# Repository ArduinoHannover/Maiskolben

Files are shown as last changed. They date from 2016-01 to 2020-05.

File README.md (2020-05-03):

# Maiskolben

## SMD Lötstation, kompatibel zu Weller-Lötspitzen

Weller baut seit Jahren *die* Lötstationen für den professionellen Bereich.
Die WMRP/WXRP-Stationen heben sich durch ihre aktiven Lötspitzen von anderen Produkten ab.
Mit einer außergewöhnlich kurzen Aufheizzeit im Sekundenbereich, einer direkt in der Spitze integrierten Temperaturmessung und dementsprechend schnelle Nachregulierung in Sekundenbruchteilen sind die Spitzen in der Industrie äußerst beliebt.
Die Spitzen selbst sind für 40€ im Handel erhältlich, die original Weller-Station kostet an die 600€.
Für den einfachen Maker oder Hobbyist auf keinen Fall ein Produkt, das beim Onlineshopping ohne weitere Überlegungen in den Warenkorb wandert.
Der *Maiskolben* hingegen ist eine erschwingliche Lösung für lediglich 40€, mit der die Spitzen ebenso angesteuert werden können.

* Betrieb mit 12V Netzteil (oder bis zu 24V mit Fertigplatine) oder 3s LiPo (Modellbau-Akku)
* Spannungsüberwachung (bei Akku für alle 3 Zellen und automatische Abschaltung bei zu geringer Ladung)
* Einfaches Wechseln von Spitzen mittels Klinken-Buchse/-Kabel
* 3 individuelle Temperatur-Presets
* Temperaturbereich von 200-450°C
* Gut ablesbares Farbdisplay mit allen nötigen Informationen
* Auto-Standby (entweder sensor- oder zeitgesteuert auf 150°C)
* Auto-Wakeup (entweder sensorgesteuert oder durch Berühren von Lötschwamm, Messingwolle oder Lötstelle)
* USB-Schnittstelle zur Überwachung oder Steuerung mittels PC
* Potentialausgleich-/ESD-Buchse (über 1MΩ an GND)
* Optisches Feedback der Heizleistung durch LED
* Open-Source-Software auf Basis von Arduino
* Software-Update kann per USB eingespielt werden

*Zu erwerben bei [HannIO](https://hannio.org).*

## Stromzufuhr

Die Stromzufuhr wird wahlweise über die Hohlstecker-Buchse (10-24V) *ODER* die JST-XH4 (11,1V) Buchse angeschlossen.
Bei Versionen < 3.0 niemals beide gleichzeitig anschließen!
Der Lötkolben (Weller RT-XX, z.B. RT-1 für feine Lötarbeiten) wird über die Klinkenbuchse mit einer Verlängerung angesteckt.

## Display

Das Display zeigt mittig in weißer Schrift die Soll-Temperatur, darunter, sofern eine Spitze eingesteckt ist, die aktuelle Ist-Temperatur.
Bei eingeschaltetem Lötkolben erscheint zusätzlich noch die Zeit, nach der sich der Lötkolben automatisch in den Standby versetzt.
Der Balken am oberen Bildschirmrand spiegelt die Ist-Temperatur wieder.
Oben Links wird die Spannung bzw. die Ladezustände der einzelnen Zellen angezeigt.
Links wird durch das Power-Symbol der aktuelle Zustand (aus = rot, Standby = gelb, an = grün) signalisiert.
Am unteren Rand sind die drei Presets zu sehen.

## Bedienung

Nach dem Anstecken von Netzteil und Lötspitze kann die Station durch halten der Power-Taste (unten rechts) eingeschaltet werden.
Basierend auf der letzten Einstellung wird die angezeigte Soll- (Power-Symbol grün) oder die Standby-Temperatur (Symbol gelb) angefahren.

Mittels der Tasten rechts vom Display (Pfeile) lässt sich die Soll-Temperatur nach oben und unten korrigieren.
Sollte einer der Pfeile auf dem Display ausgegraut sein, so lässt sich über diese Temperatur hinaus keine weitere Änderung mehr vornehmen (200 ≥ T ≥ 450).

### Presets

Mittels der Preset-Tasten unter dem Bildschirm lassen sich voreingestellte Temperaturen als Soll-Temperatur setzen und die Station gleichzeitig aus dem Standby aufwecken.
Durch Gedrückthalten einer der drei Tasten wird der dort gespeicherte Wert durch die aktuelle Soll-Temperatur überschrieben.
Wird die Power-Taste nur kurz gedrückt, so wird der Standby-Zustand umgeschaltet.

### Startmenü

Es gibt ein verstecktes Menü, in dem sich der automatische Standby abschalten und ein automatisches Hochfahren auf die zuletzt gewählte Temperatur bei Spannungsversorgung aktiviert werden können. Um in dieses Menü zu gelangen, muss beim Anlegen der Spannungsversorgung während des Blinkens der LED die Power-Taste betätigt werden.

## Fehlermeldungen

#### USB power only/Connect power supply; Power too low/Connect power >5V
Die Lötstation wird entweder nur über USB oder eine Spannungsquelle mit knapp 5V versorgt.
Zum Betrieb wird ein adäquates Netzteil oder Akku benötigt (≥40W)

#### NO TIP; No tip connected/Tip slipped out?
Es wurde keine Spitze eingesteckt oder nicht erkannt.
Es kann sein, dass die Spitze defekt ist oder nicht richtig in der Buchse steckt.

#### Temperature dropped/Tip slipped out?
Es wurde ein zu großer Temperaturabfall bemerkt und die Wahrscheinlichkeit besteht, dass die Spitze leicht aus der Buchse herausgerutscht ist.
Durch das Herausrutschen kann eine Verbindung zwischen Masse und dem Sensor hergestellt werden, sodass die erkannte Temperatur beim Offset von 24°C liegt.

#### Not heating/Weak power source or short
Entweder kann die Stromversorgung nicht genug Leistung bringen, um die Spitze in einem angemessenen Zeitraum aufzuheizen oder es liegt wie bei obigem Fehler ein Kurzschluss von Masse und Sensor vor.

#### Battery low/Replace or charge
Der Akku hat auf mindestens einer Zelle eine zu geringe Spannung und sollte ersetzt oder geladen werden.

Fehlermeldungen müssen durch OK bestätigt werden.
Die Fehlermeldungen können nicht unterdrückt werden, sollte allerdings mehrfach hintereinander eine Meldung bestätigt und die Station wieder eingeschaltet werden, kann dies zu übermäßigem Erwärmen der Lötspitze führen.

## Software-Update

Um die aktuellste Software auf den Maiskolbe zu übertragen, muss zunächst die [Arduino-IDE](https://www.arduino.cc/en/Main/Software) heruntergeladen werden.
In diesem Repository befinden sich zwei Programme, zum einen Maiskolben_LCD für die Hardware-Revision 1.0 und Maiskolben_TFT für Hardware-Revisionen ab 1.5.
Die .ino Datei kann mit Arduino geöffnet werden.
Der Serielle-Port muss nach Herstellen einer Verbindung zwischen Maiskolben und PC unter _Werkzeuge_ > _Port_ ausgewählt werden.
Unter Umständen muss zuvor noch der [CH340 Treiber](http://www.wch.cn/download/CH341SER_ZIP.html) für den USB-Seriell-Wandler installiert werden.
Als _Board_ sollte _Arduino Nano_ mit _Prozessor: ATmega328 (Old Bootloader)_ ausgewählt werden.
Über _Sketch_ > _Hochladen_ bzw. den Pfeil nach Rechts in der oberen Leiste kann das Programm übertragen werden.

### Bibliotheken

Unter Umständen müssen vorher folgende Libraries noch über _Sketch_ > _Bibliothek einbinden_ > _.ZIP Bibliothek hinzufügen..._ eingebunden werden:

* [TimerOne](https://github.com/PaulStoffregen/TimerOne)
* [PID_v1](https://github.com/br3ttb/Arduino-PID-Library/)
* ~~[Adafruit_ST7735](https://github.com/adafruit/Adafruit-ST7735-Library)~~ (Software Version < 3.0)
* [TFT_ILI9163C](https://github.com/ArduinoHannover/TFT_ILI9163C)
* [Adafruit_GFX](https://github.com/adafruit/Adafruit-GFX-Library)

Dafür muss von den entsprechenden Seiten zuvor die ZIP heruntergeladen werden.
Diese kann dann in dem Dateibrowser, der sich nach obiger Anleitung öffnet, selektiert werden.

### Changelog

* 3.1
  * Option im Menü eingebaut, um zwischen Fahrenheit und Celsius zu wechseln
  * Bug behoben, der bei falsch initialisiertem EEPROM die Temperaturberechnung nicht richtig ausgeführt hat
* 3.0
  * Geänderte Display-Bibliothek (vgl. [Abschnitt Bibliotheken](#Bibliotheken))
  * Mehr Strings im Flash statt im RAM
  * Anpassungen um einen Maiskolben V3.2 im LiPo-Betrieb vollständig abzuschalten
  * Limitierung der Minimaltemperatur auf 200°C
  * `°C` wird mit bei Soll- und Ist-Temperatur angezeigt
  * Interne Temperatur-Kalibrierung für jeden Maiskolben individuell (bisher nur für Kalibrierung ab Werk)
* 2.8
  * Zeilenhöhe des Balkens ist nun variabel
  * Temperaturen als `#define` gesetzt
  * Temperaturberechnung wieder angepasst
  * EEPROM-Fehler behoben
* 2.7
  * TFT-Reset eingebaut
* 2.6
  * Schreibfehler korrigiert
  * Anpassungen an unterschiedliche Hardwareausführungen verbessert
  * Beim Aufruf des Menüs kommt man nach schließen direkt zum Programm
  * Autopower verfeinert
* 2.5
  * Interne Testroutinen hinzugefügt
  * Anpassung an Hardwarerevision ≥ 3.0
  * Wattanzeige hinzugefügt
* 2.4
  * Spannungsanzeige gegen Steckersymbol getauscht
* 2.3
  * Anpassung an unterschiedliche Display-Treiber (BGR/RGB)
  * Geänderte Temperaturmessung
* 2.1
  * Bidirektionale Steuerung über serielle Schnittstelle
* 2.0
  * Initiale Version für GitHub (TFT)
  * Auto-Standby hinzugefügt
  * Parameter angepasst

### Achtung!

Zur eigenen Sicherheit vor einem Software-Update die Lötspitze entfernen.
Zwar wird die Heizspannung beim Übertragen deaktiviert, dennoch kann es vereinzelt zu Fehlfunktionen und dadurch bedingtem unbeschränkten Aufheizen der Spitze kommen.

Modifikationen an der Software sind auf eigene Gefahr des Nutzers.

## Umbauten

Nachfolgend werden Modifikationen beschrieben, die die Funktionen des Maiskolben erweitern.
Für eigens durchgeführte Änderungen kann keine Haftung übernommen werden.

### Ablage-Sensor nachrüsten

Statt des automatischen Standbys nach einer bestimmten Zeit kann auch der Standby durch einen Ablage-Sensor erzwungen werden.
Auf der Platine befinden sich Kontakte mit STBY, 5V und GND.
Um den Standby zu aktivieren muss STBY mit GND verbunden werden, um wieder aufzuwachen muss die Verbindung getrennt werden.
Das Schalten von STBY nach GND kann entweder durch einen Schalter erfolgen, der beim auflegen der Spitze auslöst, alternativ mit einem Hall- oder Reed-Sensor.
Für letzteres muss an dem Ende des Klinken-Kabels, an dem die Spitze eingesteckt wird, ein Magnet angebracht werden, der den Sensor dann auslöst.

### Stromversorgungs-Schalter

Ab Hardware-Revision 1.5 gibt es auf der Platinenunterseite eine Lötbrücke mit der Beschriftung ON/OFF.
Bis einschließlich Revision 1.9 wird beim Durchtrennen dieser Brücke die gesamte Stromversorgung unterbrochen.
Ab Revision 1.11 wird hingegen nur noch die Zuleitung des LiPos getrennt.
An den beiden Lötpunkten können nach dem Durchtrennen der Leiterbahn Kabel zu einem Schalter gelötet werden, mit dem sich die Stromversorgung unterbrechen lässt.

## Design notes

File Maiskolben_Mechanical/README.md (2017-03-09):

# Dateien für 3D-Druck- oder Lasercut-Gehäuse

Sofern die Dateien nicht den Zusatz "THT" enthalten, sind diese für die fertig gelöteten Station im Shop geeignet. Dateien mit "THT" hingegen nur für den Bausatz (siehe [Maiskolben_THT](https://github.com/ArduinoHannover/Maiskolben/tree/master/Maiskolben_THT)).

## Lasercut-Gehäuse

Die `_lasercut`-Dateien eignen sich für 3mm Material (klares Plexiglas wird für die Front empfohlen, alternativ Ausschnitt für das Display vorsehen). Beim THT Gehäuse sind zudem noch 6 der Button Caps (3D-Druck) notwendig.

## Eigenes/3D-Druck Gehäuse

Die `_outlines`-Dateien, respektive die .obj-Dateien sind 2D-/3D-Modelle, die zum Erstellen von eigenen Gehäusen genutzt werden können.

# Displayfix

Sollte das Display weiß bleiben (inkonsistent, selbst innerhalb einer Charge nur sporadisch) gibt es verschiedene Möglichkeiten, dies zu beheben. In der Software kann per `#define USE_TFT_RESET` der `STBY_NO` (Ablagesensor) als Resetleitung des Displays genutzt werden. Hierfür ist die Verbindung von `Reset` zwischen Arduino und 74HC4050 zu trennen und am 74HC4050 eine Verbindung zu `A1` herzustellen. Eine andere Variante ist ein RC-Glied zur Zeitverzögerung einzubauen. Hierfür wird ebenfalls die Zuleitung getrennt und ein Widerstand eingelötet. Vom Reset am 4050 (also vom Arduino aus gesehen hinter dem eingelöteten Widerstand) ist gegen Masse ein Widerstand einzulöten. Näheres dazu im Displayfix-PDF.

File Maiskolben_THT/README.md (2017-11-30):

# Maiskolben-Selfmade

## Selbstbau-Version des Maiskolben mit THT-Bauteilen

Die in diesem Ordner abgelegten Dateien sind für den Nachbau des Maiskolben mit THT-Bauteilen für die Make 5/16.

### Bauteile

| Menge | Bauteil |
---: | ---
1 | 2N700
1 | IRF5305
1 | OPA703PA (OPA336PA)
1 | 74HC4050
1 | Arduino Nano (o.vgl.)
1 | LED 5mm
1 | 220Ω (oder anderer passender Vorwiderstand für die LED)
1 | 100Ω
1 | 1kΩ
2 | 5k6Ω
5 | 10kΩ
1 | 68kΩ
1 | 100kΩ
1 | 10MΩ
2 | 100nF
2 | 10nF
ggf. | Buchsenleisten nach Bedarf
6 | Taster 6x6mm; möglichst hoch (12mm)
1 | Stereo Klinkenbuchse (EBS 35)
1 | DC Buchse (Netzteilspezifisch etwa Lumberg NEB21R)
1 | Passendes Netzteil
1 | Weller Lötspitze

Ein Großteil der Bauteile sind beim Elektronikeinzelhandel verfügbar, das Display hingegen fast ausschließlich bei [eBay](http://sndstrm.de/18tft) bestellbar (sofern nicht mehr verfügbar nach `1.8 tft` suchen, blaue Platine, **nicht** Adafruit), die [Platine oder das ganze Set kann ebenfalls online bestellt werden](https://hannio.org/produkt/maiskolben-tht/).

## Aufbau

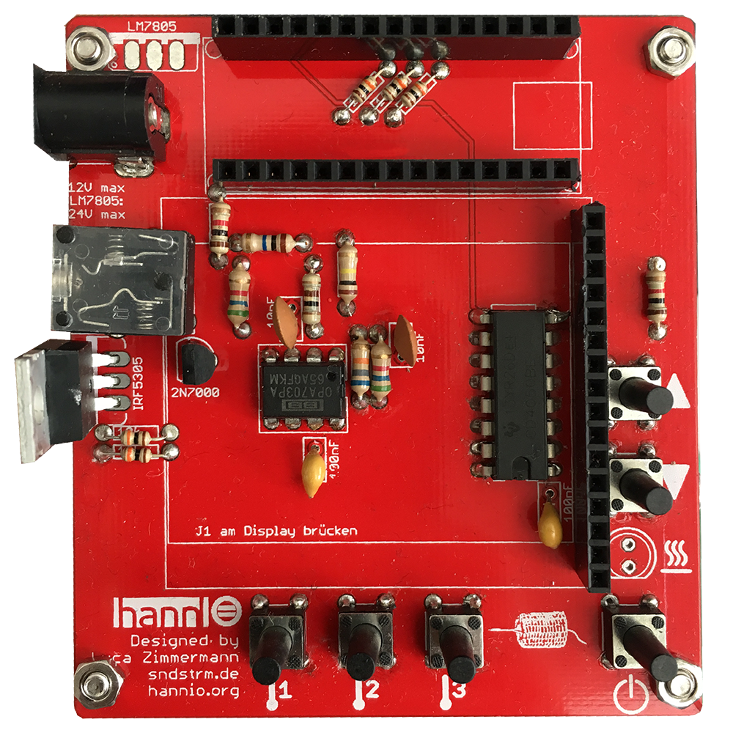
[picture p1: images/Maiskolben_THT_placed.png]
Bestückte Platine Ohne LED


Der MOSFET (IRF5305) kann unter das Display gebogen werden, dazu vorher etwas mit Klebeband isolieren, um Kontakt zu vermeiden. Den 2N7000 dafür weit genug versenken.

## Software

Für die Software bitte [die Update-Anleitung](https://github.com/ArduinoHannover/Maiskolben#software-update) zur Hilfe nehmen.

## Problembehandlung

### Display bleibt weiß
In diesem Fall arbeitet der Reset vom Display nicht sauber. Softwareseitig ist dafür `#define USE_TFT_RESET` vorgesehen. Um einen Reset vom Arduino zu triggern, muss allerdings die Reset-Leitung zwischen Arduino und Display getrennt werden.

Bei neueren Platinen gibt es dafür einen Jumper `R A` - dieser ist standardmäßig an R (Reset) angeschlossen. Diese Verbindung muss etwa mit einem Cutter aufgetrennt werden und dann eine Brücke an `A` gesetzt werden.

Ansonsten muss die Leiterbahn aufgekratzt werden oder brutal der Reset-Pin am Arduino weggeknipst werden. Dann muss die Leiterbahn zum Display mit A0 vom Arduino verbunden werden.

### Display zeigt Artefakte
Teilweise arbeitet der Spannungsregler nicht zufriedenstellend, sodass der Treiber des TFT ab und zu Spikes bekommt. In diesem Fall sollten verschiedene Kondensatoren (100nF sollte klappen) am Display VCC/GND oder auch zwischen GND und 5V ein größerer Kondensator (100uF/6,3V) eingebaut werden.

### Andere Probleme

[Fehlermeldungen](https://github.com/ArduinoHannover/Maiskolben#fehlermeldungen)

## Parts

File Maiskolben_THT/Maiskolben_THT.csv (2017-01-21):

Qty | Value | Package | Parts | Description
1 | 0R/Jumper | AXIAL-0.3 | R14 | Resistor
1 | 100R | AXIAL-0.3 | R7 | Resistor
2 | 1k | AXIAL-0.3 | R1, R5 | Resistor
2 | 5K6 | AXIAL-0.3 | R2, R8 | Resistor
5 | 10k | AXIAL-0.3 | R3, R9, R10, R11, R12 | Resistor
1 | 68K | AXIAL-0.3 | R4 | Resistor
1 | 100K | AXIAL-0.3 | R6 | Resistor
1 | 10M | AXIAL-0.3 | R18 | Resistor
2 | 10nF | CAP-PTH-SMALLEZ | C6, C8 | Capacitor
2 | 100nF | CAP-PTH-SMALLEZ | C1, C7 | Capacitor
1 | 2N7000 | TO-92 | Q2 | Common NMOSFET Parts
1 | IRF5305 | TO220V | Q1 | Generic PMOSFET
1 | LM7805TV | TO220V | IC2 | Or short SJ1 (12V max)
1 | CD4050BE | DIP16 | U1
1 | OPA703PA | DIL08 | IC1 | Rail-to-Rail Operational Amplifiers
1 | RED | LED5MM | HEATING | LED
6 | 12mm | TACTILE-PTH | S1, S2, S3, S4, S5, S6 | Momentary Switch
1 | 1.8TFT_BLUE | 1.8TFT_BLUE | TFT1
1 | ARDUINO_NANOR3 | ARDUINO-NANO | U2 | Arduino NANO R3
1 | AUDIO_JACK_5P_KB_3_SPRS | EBS_35 | J2
1 | POWER_JACKPTH | POWER_JACK_PTH | JP1 | Power Jack

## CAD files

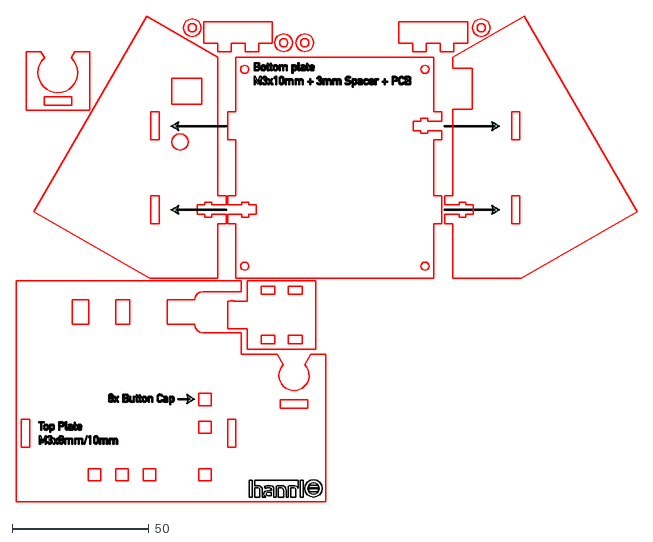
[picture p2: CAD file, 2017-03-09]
Maiskolben_Mechanical/Maiskolben_THT_Lasercut.dxf
226.8 x 177.4

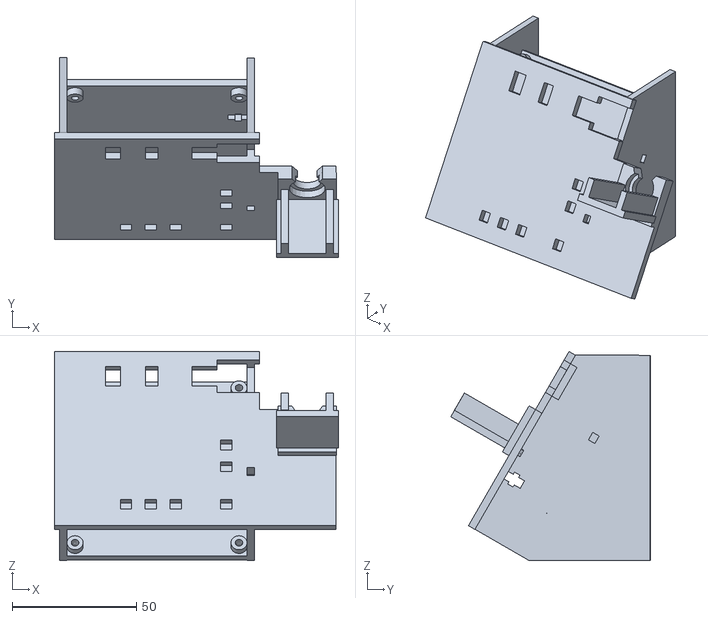
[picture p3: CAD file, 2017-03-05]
Maiskolben_Mechanical/Maiskolben_THT_Lasercut_3DView.stl
114.1 x 80.2 x 84.0

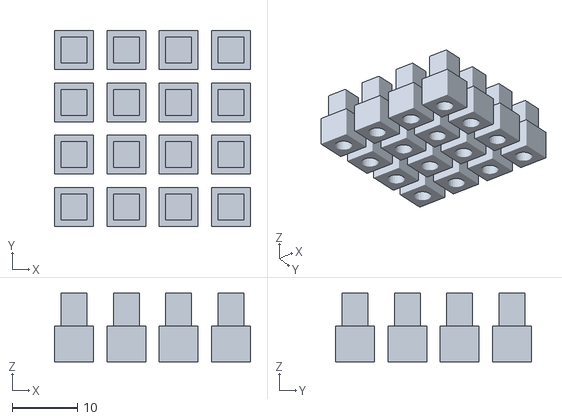
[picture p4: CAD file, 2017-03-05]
Maiskolben_Mechanical/Maiskolben_THT_Button_Cap_x16.stl
30.0 x 30.0 x 10.5

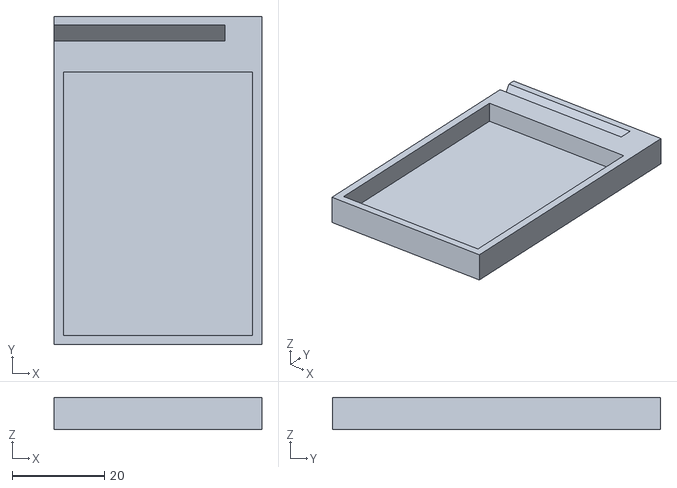
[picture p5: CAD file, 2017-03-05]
Maiskolben_Mechanical/Maiskolben_Spongeholder.stl
45.0 x 71.0 x 7.00

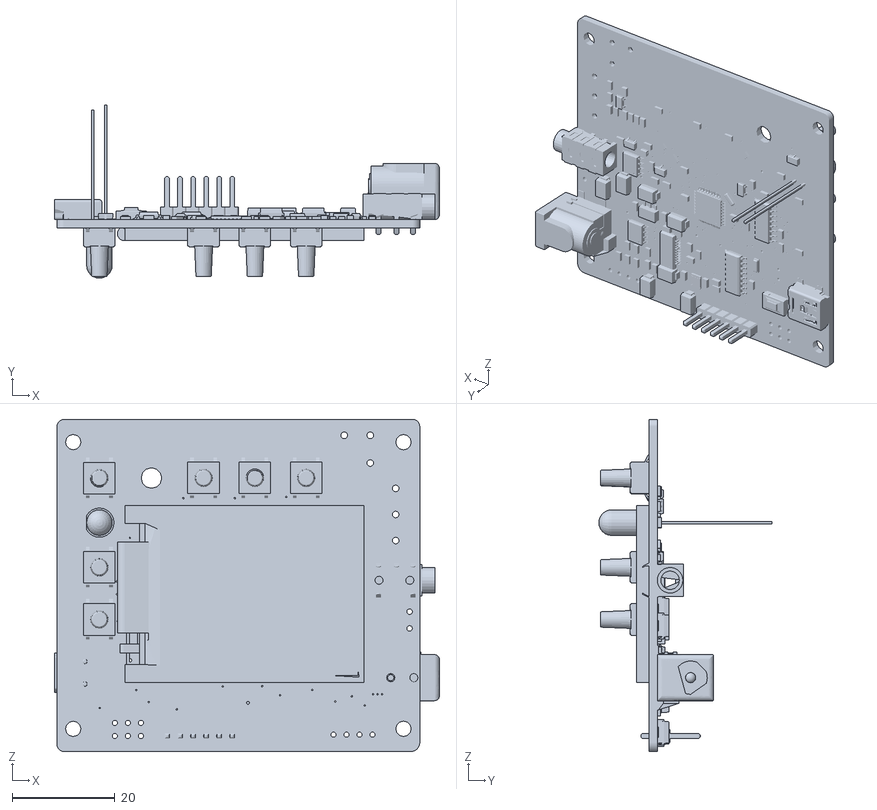
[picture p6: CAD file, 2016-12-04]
Maiskolben_Mechanical/Maiskolben.obj
75.1 x 33.8 x 64.8

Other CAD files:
Maiskolben_Mechanical/Maiskolben_outlines.dxf
Maiskolben_Mechanical/Maiskolben_Lasercut.dxf

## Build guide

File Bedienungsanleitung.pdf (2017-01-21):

Bedienungsanleitung
Lötstation „Maiskolben“

Funktionsweise
Stellen Sie mit den Pfeil-Tasten die gewünschte Soll-Temperatur ein. Langes Drücken auf die Power-Taste schaltet die Heizung der Lötspitze ein oder aus. Kurzes Drücken wechselt zwischen Standby (150°C) und aktivem Betrieb (eingestellte Temperatur). Die drei Temperaturwahlschalter laden mit kurzem Druck die angezeigte Temperatur als Soll-Temperatur. Eine Speicherung der aktuellen Soll-Temperatur ist durch gedrückthalten einer der Tasten möglich. Warnmeldungen
Im Betrieb können unterschiedliche Warnmeldungen erscheinen, die jeweils durch Drücken des Temperaturwahlschalters 3 quittiert werden können.
USB Power only: Die Station wurde vermutlich nur über ein USB-Kabel verbunden. Zum Betrieb muss eine geeignete Spannungsquelle angeschlossen werden.
NO TIP: Es ist keine Lötspitze eingesteckt oder erkannt worden, prüfen Sie die Verbindung.
Temperature dropped: Es wurde ein zu großer Spannungsabfall bemerkt, es wird vermutet, dass die Lötspitze kurzzeitig keinen Kontakt mehr hatte.
Not heating: Die Spitze heizt entweder schlechter Kontakt der Lötspitze oder ein zu schwaches Netzteil nicht [schnell] genug.
Battery Low: Der angschlossene Akku weist eine zu niedrige Zellspannung auf (siehe auch Verwendungshinweis zur
Benutzung mit Akku).
Bedienungshinweise
Die Lötstation ist eine Platine mit offenliegenden Bauteilen und Kontakten. Verhindern Sie den Kontakt mit elektrisch leitenden Objekten (z.B. Metall, Lötzinn). Verändern Sie nichts an der Platine, brühren Sie diese nicht mit einer Lötspitze. Berühren Sie im Betrieb nicht die Kontaktflächen der Bauteile.
Anschluss der Lötspitze
Verwenden Sie ausschließlich original Weller RT-Spitzen. Die Lötspitzen können über eine 3,5 mm-Klinke Verlängerungskabel an die Station angeschlossen werden. Das Kabel sollte einen genügenden Leitungsquerschnitt aufweisen. Kontrollieren Sie in regelmäßigen Abständen den Zustand der Lötspitze und ersetzen Sie diese, wenn nötig. Anschluss an Strom
Verbinden Sie ein Netzteil (2,1/5,5mm, maximal 24 V, mindestens 3,5 A) oder einen Lithium-Polymer-Akku mit 3 Zellen (Japan Standardverbinder JST-XH2,54) über die entsprechenden Buchsen mit der Station.
Die Aufheizzeit der Spitze ist abhängig von der angelegten Spannung.

Verwendungshinweis zur Benutzung mit Akku Die Station bietet eine Spannungsüberwachung der einzelnen Akku-Zellen. Ein automatisches Abschalten erfolgt darüber hinaus nicht. Bei einer Warnmeldung zum niedrigen Ladezustand (blinkende Akku-Symbole und/oder Meldung „Battery Low“) trennen Sie den Akku von der Station oder laden Sie ihn auf. Die Station sollte mit angeschlossenem Akku nie unbeaufsichtigt gelassen werden. Kontrollieren Sie regelmäßig die Temperatur des Akkus, sollte dieser zu warm werden oder sich aufblähen, trennen Sie ihn umgehend von der Station.
Laden von Akkus
Die Station ist in unterschiedlichen Ausführungen erhältlich. Sollten Sie die Station ohne Ladeschaltung erworben haben (Standard), schließen Sie nie ein Netzteil und Akku gleichzeitig an. Trennen Sie zum Laden den Akku von der Station und Laden ihn mit einem geeigneten Ladegerät. Bei der Station mit Ladeschaltung verwenden Sie ein geeignetes Netzteil und schließen dieses an die Station an. Stecken Sie den Lithium-Polymer-Akku dann an die Station. Gefahrenhinweis Akku
Trennen Sie den Akku von der Station, wenn Sie diese nicht benutzen. Durch zu starke Entladung kann es zu Reaktionen im Akku kommen, die als Folge eine mögliche Explosion nicht ausschließt.
Laden Sie Lithium-Polymer-Akkus nicht in Innenräumen sondern draußen auf feuerfestem Untergrund (Beton, Granit) und mit genügend Sicherheitsabstand (2 Meter) zu brennbaren Objekten. Lagern Sie den Akku über längere Zeiträume mit einer Zellspannung von 3,7V und kontrollieren Sie diese regelmäßig. Sollte die Spannung auf 3,65V oder weniger abfallen, laden Sie den Akku wieder etwas auf. Auch bei der Lagerung sollten keine brennbaren Objekte sich in unmittelbarer Nähe befinden, es wird ein feuerfester Umschlag empfohlen. Ersetzen Sie defekte Akkus. Aktualisierung der Software
Nur die Software im Auslieferungszustand ist von der Gewährleistung abgedeckt. Sollten Sie eine ander Software auf die Station übertragen, so ist dies auf eigene Gefahr. Hinweise zur Aktualisierung finden Sie unter hannio.org/MaiskolbenSoftware

HannIO
Luca Zimmermann
Lothringer Straße 24
30559 Hannover
hannio.org

Revision 1

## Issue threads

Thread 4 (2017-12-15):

Maiskolben (Kaufversion v2.0) Bootet nicht mehr

DrKuebel, 2017-12-15:
Hallo,

wenn der MK mit 12V versorgt wird, leuchtet das Display konstat weiss auf und die Power LED blinkt 5 mal kurz auf... mehr passiert nicht.

woran kann das liegen?

soundstorm, 2017-12-15:
Hallo,

einige Displays haben etwas Probleme damit, wenn die Pegel nicht schnell genug auf dem richtigen Level sind. Durch ein länger auf LOW gehaltenen Reset des Displays lässt sich hier Abhilfe schaffen:
https://github.com/ArduinoHannover/Maiskolben/blob/master/Maiskolben_Mechanical/Maiskolben_Displayfix.pdf
Alternativ kann auch STBY unten links auf der Platine mit dem im PDF gezeigten Pin am 4050 verbunden werden, auch hierbei muss die Leitung nach oben (da wo der 10k sonst rein sollte) getrennt werden. In der Software muss dann `#define USE_TFT_RESET` gesetzt werden:
https://github.com/ArduinoHannover/Maiskolben/blob/master/Maiskolben_Mechanical/README.md

DrKuebel, 2017-12-18:
Hallo,

Danke für die schnelle Antwort
Die von Dir angesprochene Änderung war schon eingelötet in der gelieferten Platine.

s.Foto

Gruß

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

DrKuebel, 2017-12-19:
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
Hallo,

wenn ich das richtig verstanden habe, muss ich die beiden Bauteile (gelb) entfernen und statt dessen eine Verbindung (blau) an den Lötpunkt (grün) legen.

Gruß

soundstorm, 2017-12-19:
Hallo,

genau, dies wäre mit einem Softwareupdate verbunden. Alternativ lässt sich auch der Widerstandswert erhöhen (aktuell sind 68k eingebaut).
Zunächst sollte aber geprüft werden, ob mit einem regulären Reset per rotem Taster die Initialisierung korrekt abläuft.

DrKuebel, 2017-12-19:
Hallo,

wenn ich den roten Reset an der Unterseite drücke passiert das gleiche , LED blinkt 5 mal und Bildschirm bleibt weiss.

Gruß

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

soundstorm, 2017-12-21:
Es könnte ggf. zum Ziel führen, allerdings könnte sich auch eventuell die Reset-Leitung Richtung Display gelöst haben. Sollte letzteres der Fall sein, so wird diese Lösung nicht helfen. Einen Versuch ist es jedoch wert.
Wenn der Maiskolben über USB versorgt wird, tritt das Problem ebenso auf?

DrKuebel, 2018-01-06:
gelegentlich bootet er am Win10 USB.  Am Mac bootet er in den "whitescreen"

Closed 2018-02-09.

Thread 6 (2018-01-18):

Blaue Schrift

bin101, 2018-01-18:
Hallo zusammen,

ich habe den Maiskolben HW v3.1 welcher angeblich mit der Software Version 3.0 ausgeliefert wurde.
Angeblich deshalb, da folgender Punkt:
°C wird mit bei Soll- und Ist-Temperatur angezeigt
Bei mir so nicht zutraf.

Nun wollte ich halt die neueste Version installieren, hat soweit auch alles geklappt. Nur die Tatsache, dass alles in blau ausgegeben wird stört mich ein wenig:
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

Ob ich nun HARDWARE_DEFINED_TFT auf 1 oder 2 setzte, das display setup mit der Blau/Rot Auswahl erzwinge und entsprechend bediene oder ob ich manuell den EEPROM mit RGB_DISP oder BGR_DISP beschreibe (dazu dann passend die Ausführung von setDisplayMode()) ändert leider nichts am Ergebnis und daher wollte ich hier um Hilfe fragen.

Mittlerweile habe ich eher das Gefühl, dass bei mir ein anderer TFT verbaut wurde...

bin101, 2018-01-18:
Problem gefunden:
https://github.com/ArduinoHannover/TFT_ILI9163C/commit/5ae286158f478392a631815083528f7955a27767

den colorSpace einfach nur public zu machen scheint so nicht zu funktionieren.

soundstorm, 2018-01-18:
Die letzten Änderungen wurden zwar committed aber nicht gepusht. Habe ich nachgeholt, sollte jetzt klappen 🙈

bin101, 2018-01-18:
Jupp das hat geholfen ;)

Closed 2018-01-18.

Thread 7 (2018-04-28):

kann Maiskolben_TFT nicht kompilieren

andreasloe, 2018-04-28:
Ich habe folgendes Problem und komme leider nicht weiter:

- Ich habe die Fehlermeldung in eine text-datei kopiert, das sieht ja sonst unmöglich aus. -
[Fehlermeldung.txt](https://github.com/ArduinoHannover/Maiskolben/files/1957902/Fehlermeldung.txt)

soundstorm, 2018-04-28:
Der Maiskolben ist leider nicht auf einem ESP8266 lauffähig ;-)

andreasloe, 2018-04-28:
Sorry, dann brauche ich Nachhilfe. Ich habe den vor vier Wochen gekauft und gar nicht versucht nachzubauen. Ich will den nur kompilieren, mit der arduino IDE. Anscheinend mache ich da was völlig falsch. Ich dachte, ich muss "Generic ESP8266" einstellen, was offensichtlich falsch ist. Was stelle ich ein?

soundstorm, 2018-04-28:
Nein, Arduino Nano, ATmega328 (old bootloader) :)

andreasloe, 2018-04-28:
Danke!

Closed 2018-04-28.

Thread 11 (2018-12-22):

some tweaks for the GUI / handling

coldtobi, 2018-12-22:
Hi  Luca,

Kudos for this project! The Maiskolben has become my favourite soldering tool ;-)

I've hacked a bit on the software, but I fear not everything of it might be interseting for you. So instead of making PR, I think it is better to give you a pointer to the changes and if you think something would be useful for to merge, please let me know and I will create feature based PR.

You'll find the changes on here: https://github.com/coldtobi/Maiskolben/tree/tobi

Changes you might be interested in:
**- Standby button handling:**
  2 changes:
- if station is off, ignore to go to standby mode (it would anyway not heat if not turning it on)
- I prefer that a short press of SW_STBY, when the station is off, turns it on.
This first one is commit cfbb807537a87a731e17df3c01302dc5242dc813, the second contains both and is commit b16b7bcb638001057940ab9c3655cb3868ee2664

- Some eye-candy for the color defintion.
Just a small helper macro to be able to define the colors out of rgb components, without the need
to know how many bits are for which color... commit 83a6a96c95165334cb26a9811732c61d494763cf

- A Fastboot feature (compile time switch)
Bikeshedding again, I'd like not to wait in the boot.. So this will be just a bit quicker, in the cost of that the boot screen is only shown for a short time. Commit afa4ae69345bde9c2692a0d2e0a86b2246fd5cfc

- I've got an external BMS / Charging circuit using LiFePO4 cells. For this I hacked together some coarse support to show a battery symbol with the current charge state. As my hardware is a bit wicked (I had the double-FET dying on my board, killing also a trace, so I cannot tell if that modificatin will play nice on "stock" hardware). (Those are several commits, sorry cannot name them here, but looking at the diffs should give enough hints, I hope.)

- The default voltage measurement cycle of 200ms is quite slow, especially with the FIR filter... So it takes quite some time to detect e.g fallback from external power to USB power. Commit 54647ead6f60def2a8c60014b819771d541ec2ea  makes that faster.

Let me know if there are any questions!

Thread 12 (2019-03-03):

Messung der Temperatur

3d90a9a8, 2019-03-03:
TL;DR: Wie kann ich die Lötspitze kalibrieren? Wie kann ich die Temperatur aus dem Spannungswert berechnen?

Guten Tag,

ich versuche zur Zeit mit dem Schaltplan aus der Make 5/2016 einen Maiskolben zu bauen. Ich habe den Bauvorschlag zwar abgewandelt, den OP-Amp und die MOSFETs habe ich aber unverändert aus dem Schaltplan übernommen. Mein Projekt funktioniert also ähnlich, ich kann aber nicht die mitgelieferte Firmware verwenden.

Ich habe einige Fragen bezüglich der Temperaturmessung an der Spitze. Das Lesen vom Quellcode hat mir dabei nicht wirklich weitergeholfen.

Zum einen ist mir nicht ganz klar, wie der gemessene Wert am ADC-Pin des Arduinos mit der Temperatur zusammenhängt. Ist die Spannungsveränderung linear, führt also das verdoppeln der Temperatur zur doppelten Spannung? Gibt es eine Formel, mit der ich die Temperatur aus der Spannung berechnen kann? Im Quellcode habe ich dazu `adc * 0.530805 + 38.9298` gefunden, mit meinen gemessenen Spannungswerten bin ich aber nicht auf realistische Temperaturen gekommen. Als ich bei einem Test die Lötspitze mit einem Feuerzeug erwärmt habe, hat der Arduino in etwa den Wert 100 am ADC-Pin gemessen, was einer Spannung von 0,48V entspricht.

Gibt es außerdem eine Methode, mit der ich die gemessenen Werte überprüfen und so die Lötspitze kalibrieren kann? Ich habe kein Thermometer, das derart hohe Temperaturen aushält.

Sollte ich auf andere Dinge aufpassen, wenn ich eine eigene Firmware für den Lötkolben bauen will?

Vielen Dank

AlfredoCubitos, 2021-11-20:
schau doch mal hier
http://www.martin-kumm.de//smd_solder_station/rt_solder_station_v1_1.ino
ggf. hilft das weiter

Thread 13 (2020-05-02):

How to upload new firmware?

ventilator, 2020-05-02:
Hi,

is there a setting which I am missing to upload a new firmware?
I can connect to the Maiskolben and read the serial console with the Arduino IDE - but when I click on upload, the Maiskolben just immediatly reboots. And then nothing happens for 2 minutes until "An error occurred while uploading the sketch" is written into the console

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

ventilator, 2020-05-03:
Got it running. Trick is to select "Processor ATmega328P -> Old Bootloader
The "new" bootloader was introduced in 2018. Can you update your readme?

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

Closed 2020-05-03.

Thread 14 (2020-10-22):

Besser verfügbare Alternative für OPA703PA/OPA336PA

phako, 2020-10-22:
* Den OPA703PA findet man nur entweder als China-Klon auf eBay oder im 5er Pack bei RS-Online
* Der OPA336PA ist EOL

Gibt es Alternativen, die man auch bei den üblichen Verdächtigen (Conrad, Reichelt, etc.pp.) bekommt?
Oder Alternativ: Welche Werte des OpAmps sind die wichtigen?

Andy79881, 2024-02-17:
OPA340UA verfügbar bei Reichelt mit ähnlichen Eigenschaften wie der OPA703PA

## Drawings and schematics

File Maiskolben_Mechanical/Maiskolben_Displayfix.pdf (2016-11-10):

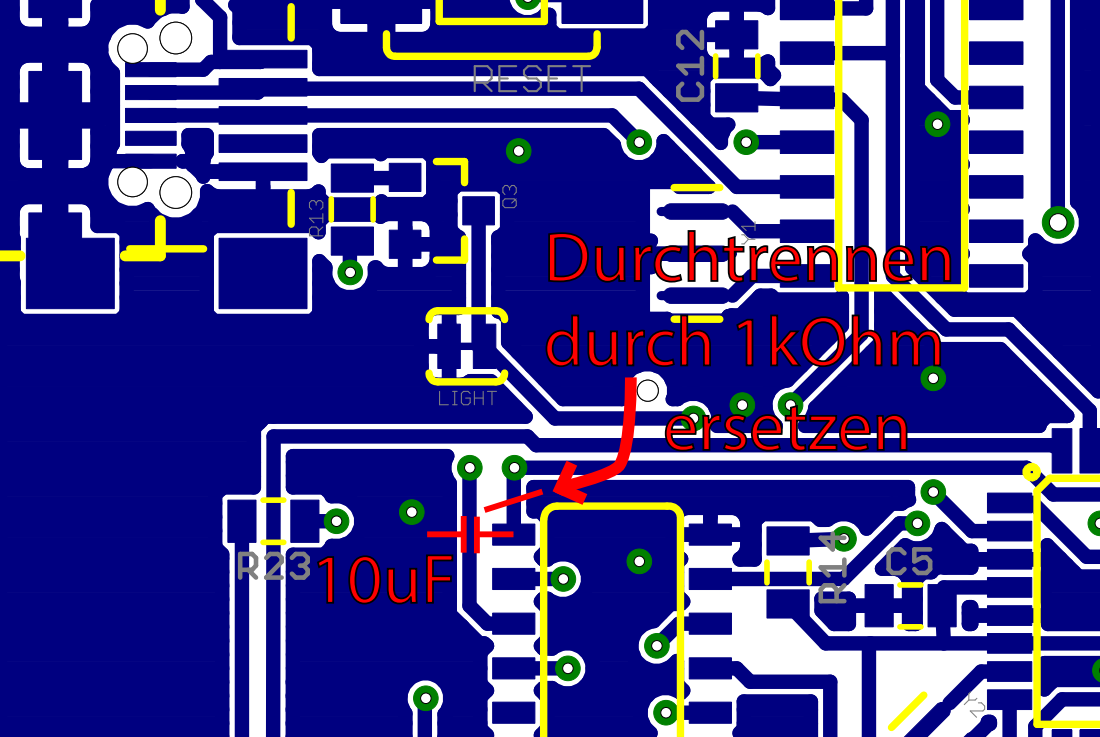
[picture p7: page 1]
Durchtrennen durch 1kOhm ersetzen

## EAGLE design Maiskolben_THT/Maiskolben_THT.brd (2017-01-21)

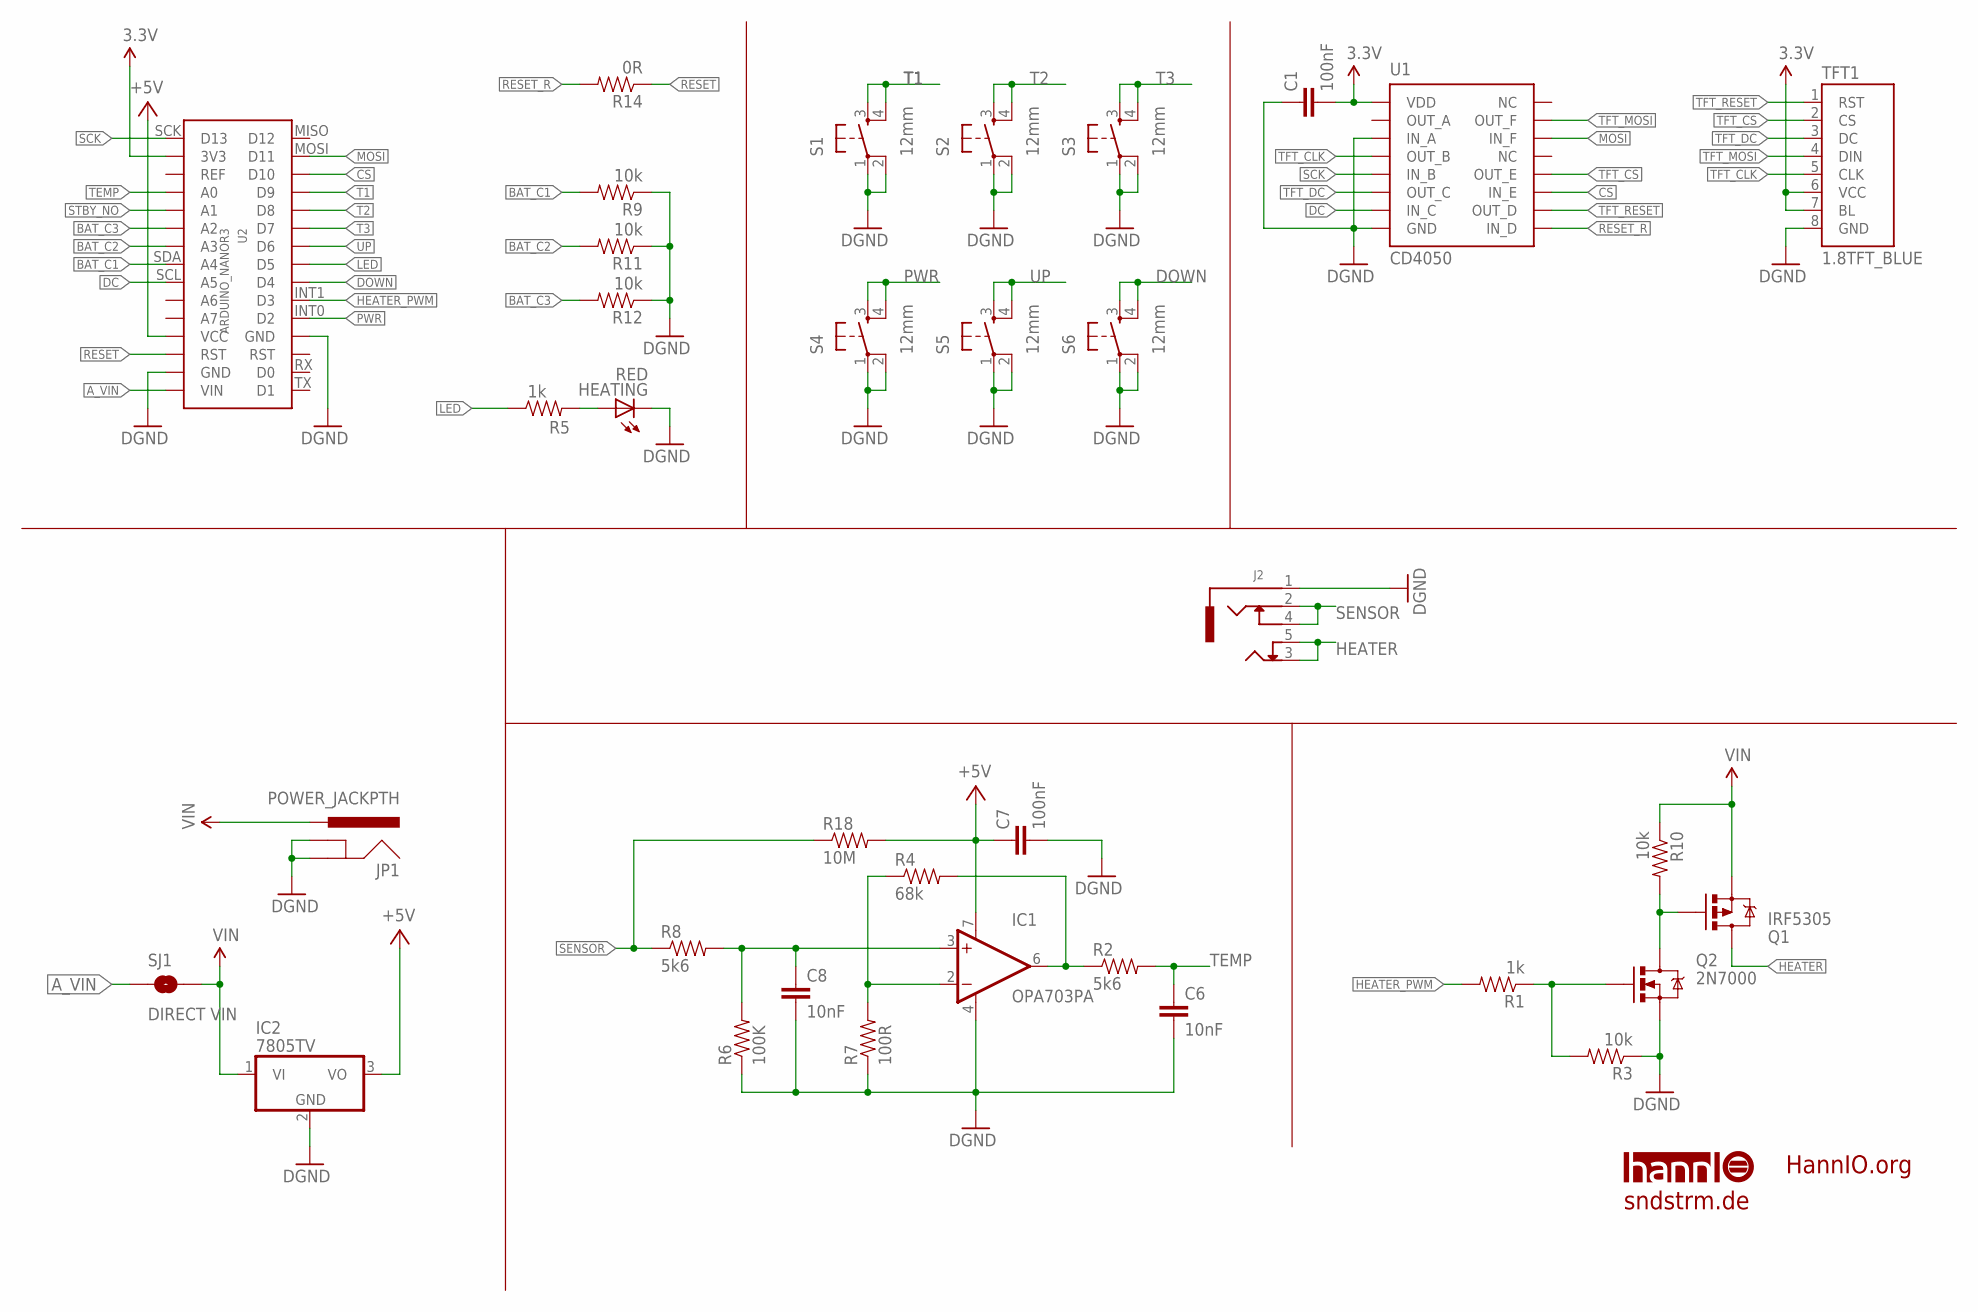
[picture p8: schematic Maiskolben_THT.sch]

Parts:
C1, C7: 100nF; CAP-PTH-SMALLEZ
C6, C8: 10nF; CAP-PTH-SMALLEZ
HEATING: RED; LED5MM
IC1: OPA703PA; DIL08
IC2: 7805TV; TO220V
J2: AUDIO_JACK_5PEBS_35; EBS_35
JP1: POWER_JACKPTH; POWER_JACK_PTH
Q1: IRF5305; TO220V
Q2: 2N7000; TO-92
R1, R5: 1k; AXIAL-0.3
R2, R8: 5k6; AXIAL-0.3
R3, R9, R10, R11, R12: 10k; AXIAL-0.3
R4: 68k; AXIAL-0.3
R6: 100K; AXIAL-0.3
R7: 100R; AXIAL-0.3
R14: 0R; AXIAL-0.3
R18: 10M; AXIAL-0.3
S1, S2, S3, S4, S5, S6: 12mm; TACTILE-PTH
SJ1: DIRECT VIN; PAD-JUMPER-2-NO_YES_SILK
TFT1: 1.8TFT_BLUE
U1: CD4050DIP16; CD4050
U2: ARDUINO_NANOR3; ARDUINO-NANO
U$1: HANNIO_MEDIUM

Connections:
3.3V: C1.2, TFT1.6 (VCC), TFT1.7 (BL), U1.VDD, U2.3V3
+5V: C7.1, IC1.7 (V+), IC2.3 (VO), R18.P$2 (2), U2.VCC
A_VIN: SJ1.1, U2.VIN
BAT_C1: R9.P$2 (2), U2.SDA (A4)
BAT_C2: R11.P$2 (2), U2.A3
BAT_C3: R12.P$2 (2), U2.A2
CS: U1.IN_E, U2.D10
DC: U1.IN_C, U2.SCL (A5)
DGND: C1.1, C6.2, C7.2, C8.2, HEATING.K (C), IC1.4 (V-), IC2.2 (GND), J2.1 (GND), JP1.GND, JP1.GNDBREAK, Q2.1 (S), R3.P$1 (1), R6.P$1 (1), R7.P$1 (1), R9.P$1 (1), R11.P$1 (1), R12.P$1 (1), S1.1, S1.2, S2.1, S2.2, S3.1, S3.2, S4.1, S4.2, S5.1, S5.2, S6.1, S6.2, TFT1.8 (GND), U1.GND, U1.IN_A, U2.GND@1 (GND), U2.GND@2 (GND)
DOWN: S6.3, S6.4, U2.D4
HEATER: J2.3 (TIP), J2.5 (TIP_NC), Q1.2 (D)
HEATER_PWM: R1.P$2 (2), U2.INT1 (D3)
HEAT_LED: HEATING.A, R5.P$2 (2)
LED: R5.P$1 (1), U2.D5
MOSI: U1.IN_F, U2.MOSI (D11)
unnamed: Q2.2 (G), R1.P$1 (1), R3.P$2 (2)
OPA+: C8.1, IC1.3 (+IN), R6.P$2 (2), R8.P$2 (2)
OPA-: IC1.2 (-IN), R4.P$1 (1), R7.P$2 (2)
OPA_OUT: IC1.6 (OUT), R2.P$1 (1), R4.P$2 (2)
PMOS_IN: Q1.1 (G), Q2.3 (D), R10.P$2 (2)
PWR: S4.3, S4.4, U2.INT0 (D2)
RESET: R14.P$1 (1), U2.RST@2 (RST)
RESET_R: R14.P$2 (2), U1.IN_D
SCK: U1.IN_B, U2.SCK (D13)
SENSOR: J2.2 (RING), J2.4 (RING_NC), R8.P$1 (1), R18.P$1 (1)
STBY_NO: U2.A1
T1: S1.3, S1.4, U2.D9
T2: S2.3, S2.4, U2.D8
T3: S3.3, S3.4, U2.D7
TEMP: C6.1, R2.P$2 (2), U2.A0
TFT_CLK: TFT1.5 (CLK), U1.OUT_B
TFT_CS: TFT1.2 (CS), U1.OUT_E
TFT_DC: TFT1.3 (DC), U1.OUT_C
TFT_MOSI: TFT1.4 (DIN), U1.OUT_F
TFT_RESET: TFT1.1 (RST), U1.OUT_D
UP: S5.3, S5.4, U2.D6
VIN: IC2.1 (VI), JP1.PWR, Q1.3 (S), R10.P$1 (1), SJ1.2

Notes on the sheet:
HannIO.org
sndstrm.de

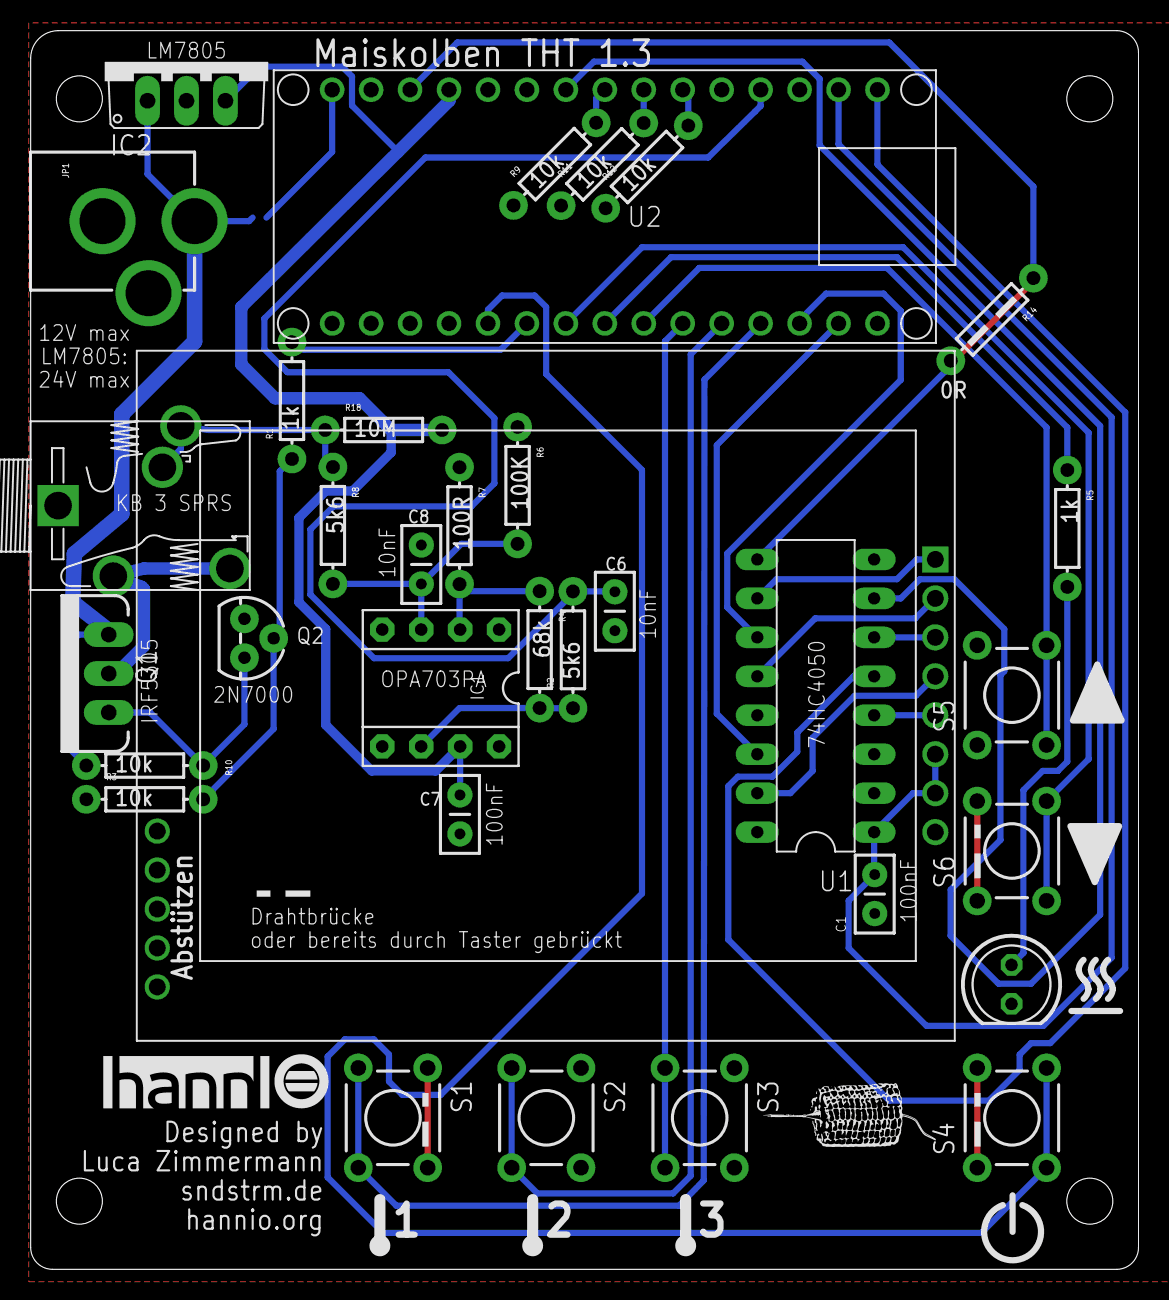
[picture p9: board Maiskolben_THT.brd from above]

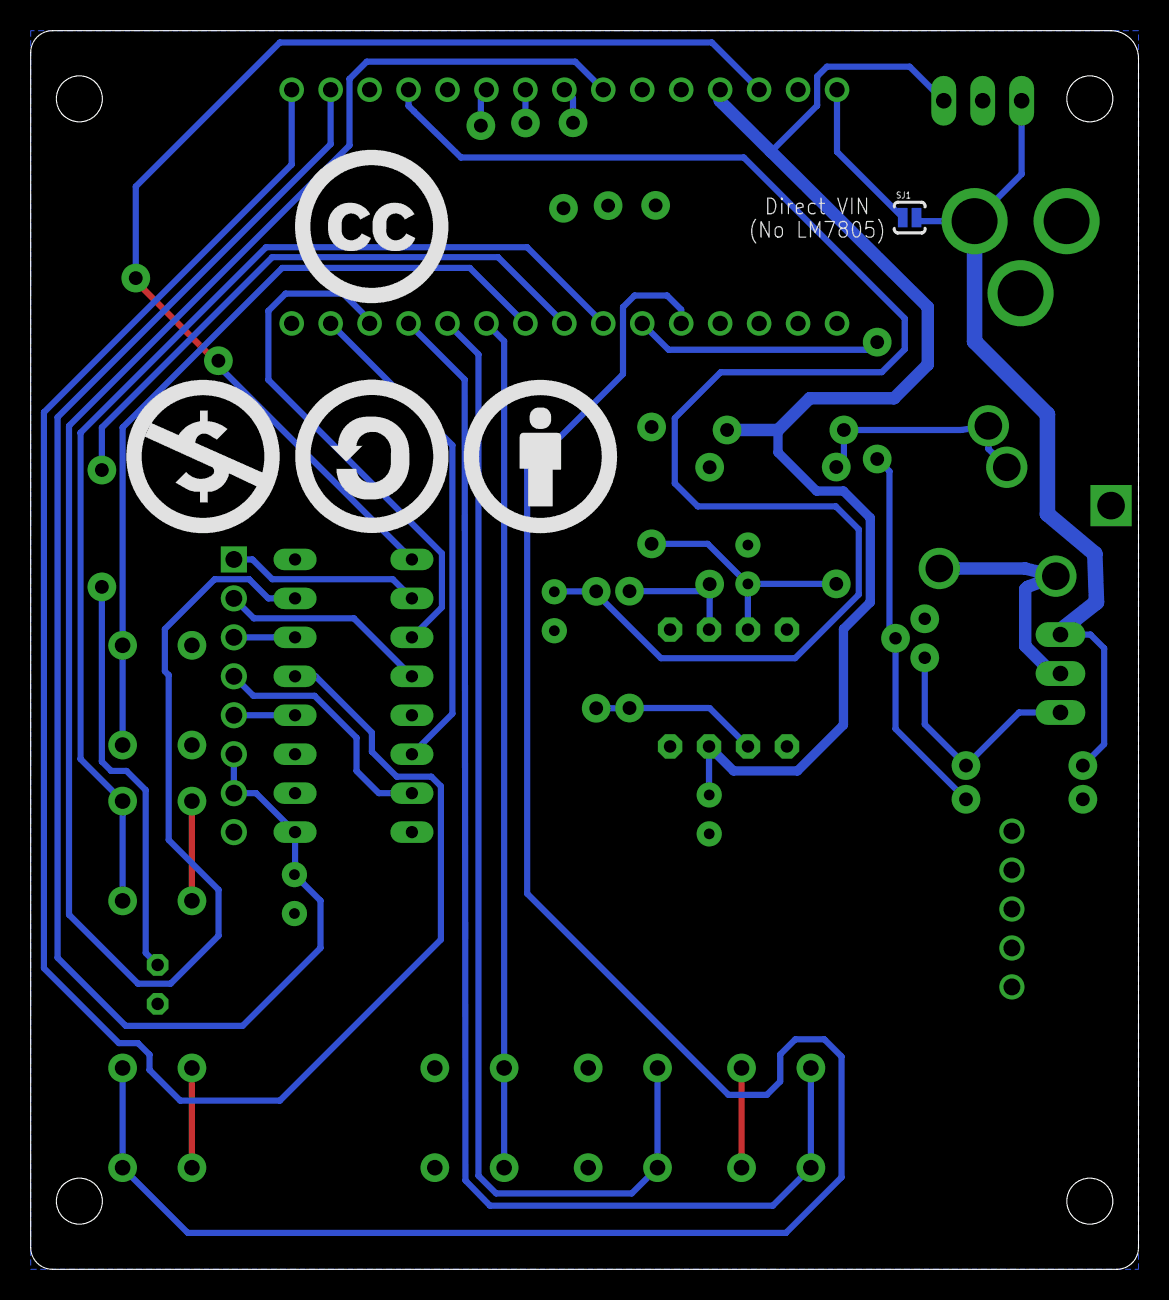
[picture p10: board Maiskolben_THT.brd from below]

Board: 2 copper layers, 72.2 x 80.8 mm, 41 parts (5 on the bottom side), 36 nets.

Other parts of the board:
U$2: MAISKOLBEN
U$4: BY_TPLACE
U$5: SA_TPLACE
U$6: NC_TPLACE
U$7: CC_TPLACE

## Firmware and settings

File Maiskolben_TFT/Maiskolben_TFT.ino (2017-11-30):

#include <SPI.h>
#include <TFT_ILI9163C.h>
#include <PID_v1.h>
#include <EEPROM.h>
#include "TimerOne.h"
#include "definitions.h"

/*
 * If your display stays white, uncomment this.
 * Cut reset trace (on THT on upper layer/0R), connect STBY_NO (A1) with reset of TFT (at 4050).
 * See also readme in mechanical folder for reference.
 */
//#define USE_TFT_RESET

/*
 * If red is blue and blue is red change this
 * If not sure, leave commented, you will be shown a setup screen
 */
//#define HARDWARE_DEFINED_TFT 2
/*
 * Based on your Hardware-Revision there may be modifications to the PCB. 
 * In V3 and up is a second voltage measurement circuit.
 * HW REVS:
 * 1.5 - 2.8:
 * For THT this should be set to anything < 3
 * Normally leave this commented as it is stored in EEPROM
 */

// V 1.5 - 2.11, Maiskolben THT
//#define HARDWARE_REVISION     2
// V 3.0 and 3.1
//#define HARDWARE_REVISION     3

/*
 * Only used for testing, do not use.
 */
//#define INSTALL
//#define TEST_ADC

volatile boolean off = true, stby = true, stby_layoff = false, sw_stby_old = false, sw_up_old = false, sw_down_old = false, clear_display = true, store_invalid = true, menu = false;
volatile uint8_t pwm, threshold_counter;
volatile int16_t cur_t, last_measured;
volatile error_type error = NO_ERROR;
error_type error_old;
int16_t stored[3] = {300, 350, 450}, set_t = TEMP_MIN, set_t_old, cur_t_old, target_t;
double pid_val, cur_td, set_td;
uint8_t store_to = 255;
p_source power_source, power_source_old = NO_INIT;
boolean blink;
uint16_t cnt_measure_voltage, cnt_compute, cnt_sw_poll, cnt_but_press, cnt_off_press, cnt_but_store;
float v_c1, v_c2, v_c3, v_in, v;
uint8_t array_index, array_count;
uint32_t sendNext;
uint32_t last_temperature_drop;
uint32_t last_on_state;
boolean wasOff = true, old_stby = false;
boolean autopower = true, bootheat = false, fahrenheit = false;
uint8_t revision = 1;
boolean menu_dismissed = false;
boolean autopower_repeat_under = false;
boolean force_redraw = false;
boolean power_down = false;
uint16_t charge = 0;
float adc_offset = ADC_TO_TEMP_OFFSET;
float adc_gain = ADC_TO_TEMP_GAIN;

#define RGB_DISP 0x0
#define BGR_DISP 0x2

#ifdef USE_TFT_RESET
TFT_ILI9163C tft = TFT_ILI9163C(TFT_CS,  TFT_DC, STBY_NO);
#else
TFT_ILI9163C tft = TFT_ILI9163C(TFT_CS,  TFT_DC);
#endif
#define	BLACK   0x0000
#define	BLUE    0x001F
#define	RED     0xF800
#define	GREEN   0x07E0
#define CYAN    0x07FF
#define MAGENTA 0xF81F
#define YELLOW  0xFFE0  
#define WHITE   0xFFFF
#define GRAY    0x94B2

PID heaterPID(&cur_td, &pid_val, &set_td, kp, ki, kd, DIRECT);

void setup(void) {
	digitalWrite(HEATER_PWM, LOW);
	pinMode(HEATER_PWM, OUTPUT);
	pinMode(POWER, INPUT_PULLUP);
	pinMode(HEAT_LED, OUTPUT);
	digitalWrite(HEAT_LED, HIGH);
	pinMode(TEMP_SENSE, INPUT);
	pinMode(SW_T1, INPUT_PULLUP);
	pinMode(SW_T2, INPUT_PULLUP);
	pinMode(SW_T3, INPUT_PULLUP);
	pinMode(SW_UP, INPUT_PULLUP);
	pinMode(SW_DOWN, INPUT_PULLUP);
	pinMode(STBY_NO, INPUT_PULLUP);
	pinMode(SW_STBY, INPUT_PULLUP);
	pinMode(TFT_CS, OUTPUT);
	digitalWrite(TFT_CS, HIGH);
	Serial.begin(115200);
	
	boolean force_menu = false;
	if (EEPROM.read(0) != EEPROM_CHECK) {
		EEPROM.update(0, EEPROM_CHECK);
		updateEEPROM();
		force_menu = true;
	}
	tft.begin();
#ifdef HARDWARE_DEFINED_TFT
	#if HARDWARE_DEFINED_TFT == 1
		EEPROM.update(EEPROM_DISPLAY, RGB_DISP);
		setDisplayMode(0);
	#else
		EEPROM.update(EEPROM_DISPLAY, BGR_DISP);
		setDisplayMode(1);
	#endif
#else
	if (force_menu || EEPROM.read(EEPROM_VERSION) < 23 || EEPROM.read(EEPROM_VERSION) == 255 || (EEPROM.read(EEPROM_DISPLAY) != BGR_DISP && EEPROM.read(EEPROM_DISPLAY) != RGB_DISP)) {
		tft.fillScreen(BLACK);
		setDisplayMode(1);
		tft.setTextSize(2);
		tft.setCursor(0,0);
		tft.setTextColor(WHITE);
		tft.print(F("What color is displayed?"));
		tft.setCursor(10,112);
		tft.setTextColor(RED);
		tft.print("RED     BLUE");
		while (true) {
			if (!digitalRead(SW_T1)) {
				EEPROM.update(EEPROM_DISPLAY, BGR_DISP);
				setDisplayMode(1);
				break;
			}
			if (!digitalRead(SW_T3)) {
				EEPROM.update(EEPROM_DISPLAY, RGB_DISP);
				setDisplayMode(0);
				break;
			}
		}
		tft.fillScreen(BLACK);
		tft.setTextColor(YELLOW);
		tft.drawBitmap(0, 20, maiskolben, 160, 64, YELLOW);
		tft.setCursor(20,86);
		tft.setTextColor(YELLOW);
		tft.setTextSize(2);
		tft.print("Maiskolben");
		tft.setCursor(35,104);
		tft.print("Welcome!");
		delay(4000);
		while (!digitalRead(SW_T3) || !digitalRead(SW_T1)) delay(100);
	} else {
		setDisplayMode(EEPROM.read(EEPROM_DISPLAY) == BGR_DISP);
	}
#endif
#ifdef INSTALL
	if (EEPROM.read(EEPROM_INSTALL) != EEPROM_CHECK) {
		tft.fillScreen(BLACK);
		tft.setTextColor(RED, BLACK);
		tft.setCursor(0,0);
		tft.setTextSize(2);
		tft.println("Installation");
		for (int16_t i = -255; i < 256; i++) {
			analogWrite(HEAT_LED, 255-abs(i));
			delay(1);
		}
		uint16_t adc1 = 0, adc2 = 0;
		while (digitalRead(SW_STBY)) {
			int t = getTemperature();
			uint16_t adc = analogRead(TEMP_SENSE);
			Serial.println(t);
			digitalWrite(HEATER_PWM, !digitalRead(SW_T1) | !digitalRead(SW_T2) | !digitalRead(SW_T3)/* | !digitalRead(SW_UP) | !digitalRead(SW_DOWN)*/);
			if (!digitalRead(SW_DOWN)) {
				if (!adc) {
					digitalWrite(HEATER_PWM, HIGH);
				} else {
					adc1 = adc;
				}
			}
			if (!digitalRead(SW_UP)) {
				if (!adc) {
					digitalWrite(HEATER_PWM, HIGH);
				} else {
					adc2 = adc;
				}
			}
			tft.setCursor(0,18);
			tft.print(t);
			tft.println("  ");
			tft.print(adc);
			tft.println("   ");
			tft.println(adc * adc_gain + adc_offset);
			if (adc1 != 0 && adc2 != 0) {
				adc_gain = DELTA_REF_T / (float)(adc2 - adc1);
				adc_offset = REF_T1 - adc_gain * adc1;
				tft.println(adc_gain);
				tft.println(adc_offset);
			}
			delay(50);
		}
		EEPROM.update(EEPROM_OPTIONS,  (fahrenheit << 2) | (bootheat << 1) | autopower);
		EEPROM.update(EEPROM_VERSION, EE_VERSION);
		EEPROM.update(EEPROM_INSTALL, EEPROM_CHECK);
		EEPROM.put(EEPROM_ADCTTG, adc_gain);
		EEPROM.put(EEPROM_ADCOFF, adc_offset);
		
		tft.println("done.");
		delay(1000);
		asm volatile("jmp 0");
	}
#endif
	if (EEPROM.read(EEPROM_VERSION) != EE_VERSION) {
		force_menu = true;
	}
	tft.fillScreen(BLACK);
	uint8_t options = EEPROM.read(EEPROM_OPTIONS);
	autopower = options & 1;
	bootheat = options & 2;
	fahrenheit = options & 4;
	if (force_menu) optionMenu();
	else {
		updateRevision();
		tft.drawBitmap(0, 20, maiskolben, 160, 64, YELLOW);
		tft.setCursor(20,86);
		tft.setTextColor(YELLOW);
		tft.setTextSize(2);
		tft.print("Maiskolben");
		tft.setCursor(50,110);
		tft.setTextSize(1);
		tft.print("Version ");
		tft.print(VERSION);
		tft.setCursor(46,120);
		tft.print("HW Revision ");
		tft.print(revision);
		//Allow Options to be set at startup
		delay(100);
		attachInterrupt(digitalPinToInterrupt(SW_STBY), optionMenu, LOW);
		for (int i = 0; i < 10 && !menu_dismissed; i++) {
			digitalWrite(HEAT_LED, i % 2);
			delay(250);
		}
		detachInterrupt(digitalPinToInterrupt(SW_STBY));
	}
	/*
	 * lower frequency = noisier tip
	 * higher frequency = needs higher pwm
	 */
	//PWM Prescaler = 1024 31Hz
	//TCCR2B = (TCCR2B & 0b11111000) | 7;
	//PWM Prescaler = 256 122Hz
	//TCCR2B = (TCCR2B & 0b11111000) | 6;
	//PWM Prescaler = 128 245Hz
	TCCR2B = (TCCR2B & 0b11111000) | 5;
	//PWM Prescaler = 64  490Hz
	//TCCR2B = (TCCR2B & 0b11111000) | 4
	//PWM Prescaler = 32  980Hz
	//TCCR2B = (TCCR2B & 0b11111000) | 3;
	//PWM Prescaler = 8  3.9kHz
	//TCCR2B = (TCCR2B & 0b11111000) | 2
	//PWM Prescaler = 1    31kHz - no Noise
	//TCCR2B = (TCCR2B & 0b11111000) | 1;
	stby = EEPROM.read(1);
	for (uint8_t i = 0; i < 3; i++) {
		stored[i] = EEPROM.read(2+i*2) << 8;
		stored[i] |= EEPROM.read(3+i*2);
	}
	set_t = EEPROM.read(EEPROM_SET_T) << 8;
	set_t |= EEPROM.read(EEPROM_SET_T+1);

	for (uint8_t i = 0; i < 50; i++)
		measureVoltage(); //measure average 50 times to get realistic results
	
	tft.fillScreen(BLACK);
	last_measured = getTemperature();
	Timer1.initialize(1000);
	Timer1.attachInterrupt(timer_isr);
	heaterPID.SetMode(AUTOMATIC);
	sendNext = millis();
	if (bootheat) {
		threshold_counter = TEMP_UNDER_THRESHOLD;
		setOff(false);
	}
	if (EEPROM.read(EEPROM_ADCTTG) == 255) { //Override unset values from older versions
		EEPROM.put(EEPROM_ADCTTG, adc_gain);
		EEPROM.put(EEPROM_ADCOFF, adc_offset);
	}
	EEPROM.get(EEPROM_ADCTTG, adc_gain);
	EEPROM.get(EEPROM_ADCOFF, adc_offset);
}

void updateRevision(void) {	
#if (HARDWARE_REVISION > 2)
	EEPROM.update(EEPROM_REVISION, HARDWARE_REVISION);
	revision = 3;
#else
	if (EEPROM.read(EEPROM_VERSION) < 26 || EEPROM.read(EEPROM_REVISION) > 100) {
		EEPROM.update(EEPROM_REVISION, 2);
		revision = 2;
	} else {
		revision = EEPROM.read(EEPROM_REVISION);
	}
#endif
}

void setDisplayMode(boolean bgr) {
	tft.colorSpace(bgr);
	tft.setRotation(3);
}

void optionMenu(void) {
	tft.fillScreen(BLACK);
	digitalWrite(HEAT_LED, LOW);
	tft.setTextSize(2);
	tft.setCursor(0,0);
	tft.setTextColor(WHITE);
	tft.println("Options\n");
	tft.setTextColor(WHITE);
	tft.setCursor(10,112);
	tft.print("ON  OFF EXIT");
	uint8_t options = 3;
	uint8_t opt = 0;
	boolean redraw = true;
	while (true) {
		if (redraw) {
			tft.setCursor(0,36);
			#ifdef SHUTOFF_ACTIVE
				tft.setTextColor(autopower?GREEN:RED);
			#else
				tft.setTextColor(GRAY);
			#endif
			tft.println(" Autoshutdown");
			#ifdef BOOTHEAT_ACTIVE
				tft.setTextColor(bootheat?GREEN:RED);
			#else
				tft.setTextColor(GRAY);
			#endif
			tft.println(" Heat on boot");
			tft.setTextColor(fahrenheit?GREEN:RED);
			tft.println(" Fahrenheit");
			
			tft.setCursor(0, (opt+2)*18);
			tft.setTextColor(WHITE);
			tft.print(">");
			redraw = false;
		}
		if (!digitalRead(SW_UP)) {
			tft.setCursor(0, (opt+2)*18);
			tft.setTextColor(BLACK);
			tft.print(">");
			opt = (opt+options-1)%options;
			while (!digitalRead(SW_UP)) delay(100);
			redraw = true;
		}
		if (!digitalRead(SW_DOWN)) {
			tft.setCursor(0, (opt+2)*18);
			tft.setTextColor(BLACK);
			tft.print(">");
			opt = (opt+1)%options;
			while (!digitalRead(SW_DOWN)) delay(100);
			redraw = true;
		}
		if (!digitalRead(SW_T1)) {
			switch (opt) {
				case 0: autopower = 1; break;
				case 1: bootheat = 1; break;
				case 2: fahrenheit = 1; break;
			}
			redraw = true;
		}
		if (!digitalRead(SW_T2)) {
			switch (opt) {
				case 0: autopower = 0; break;
				case 1: bootheat = 0; break;
				case 2: fahrenheit = 0; break;
			}
			redraw = true;
		}
		if (!digitalRead(SW_T3)) break;
	}
	EEPROM.update(EEPROM_OPTIONS, (fahrenheit << 2) | (bootheat << 1) | autopower);
	updateRevision();
	EEPROM.update(EEPROM_VERSION, EE_VERSION);
	if (EEPROM.read(EEPROM_VERSION) < 30) {
		EEPROM.put(EEPROM_ADCTTG, ADC_TO_TEMP_GAIN);
		EEPROM.put(EEPROM_ADCOFF, ADC_TO_TEMP_OFFSET);
	}
	menu_dismissed = true;
}

void updateEEPROM(void) {
	EEPROM.update(1, stby);
	for (uint8_t i = 0; i < 3; i++) {
		EEPROM.update(2+i*2, stored[i] >> 8);
		EEPROM.update(3+i*2, stored[i] & 0xFF);
	}
	EEPROM.update(8, set_t >> 8);
	EEPROM.update(9, set_t & 0xFF);
	EEPROM.update(EEPROM_OPTIONS, (fahrenheit << 2) | (bootheat << 1) | autopower);
}

void powerDown(void) {
	if (power_source != POWER_LIPO) {
		power_down = false;
		return;
	}
	//Timer1.stop();
	setOff(true);
	delay(10);
	tft.fillScreen(BLACK);
	tft.setTextSize(4);
	tft.setTextColor(RED);
	tft.setCursor(50,40);
	tft.print("OFF");
	delay(3000);
	SPI.end();
	digitalWrite(POWER, LOW);
	pinMode(POWER, OUTPUT);
	delay(100);
	force_redraw = true;
	power_down = false;
	Timer1.start(); //unsuccessful
}

float toFahrenheit(float t) {
	return t * 1.8 + 32;
}

int getTemperature(void) {
	analogRead(TEMP_SENSE);//Switch ADC MUX
	uint16_t adc = median(TEMP_SENSE);
#ifdef TEST_ADC
	Serial.println(adc);
#endif
	if (adc >= 900) { //Illegal value, tip not plugged in - would be around 560deg
		analogWrite(HEATER_PWM, 0);
		if (!off)
			setError(NO_TIP);
		return 999;
	} else {
		analogWrite(HEATER_PWM, pwm); //switch heater back to last value
	}
	//return round(adc < 210 ? (((float)adc) * 0.530805 + 38.9298) : (((float)adc) * 0.415375 + 64.6123)); //old conversion
	return round(((float) adc) * adc_gain + adc_offset);
}

void measureVoltage(void) {
	analogRead(BAT_C1); //Switch analog MUX before measuring
	v_c1 = v_c1*.9+(analogRead(BAT_C1)*5/1024.0)*.1; //no divisor
	analogRead(BAT_C2);
	v_c2 = v_c2*.9+(analogRead(BAT_C2)*5/512.0)*.1; //divisor 1:1 -> /2
	analogRead(BAT_C3);
	v_c3 = v_c3*.9+(analogRead(BAT_C3)*(5.0*3.0)/1024.0)*.1; //maximum measurable is ~15V
	v = v_c3;
	if (revision < 3) return;
#ifdef VIN
	analogRead(VIN);
	v_in = v_in*.9+(analogRead(VIN)*25/1024.0)*.1; //maximum measurable is ~24.5V
	v = v_in; //backwards compatibility
#endif
}

uint16_t median(uint8_t analogIn) {
	uint16_t adcValue[3];
	for (uint8_t i = 0; i < 3; i++) {
		adcValue[i] = analogRead(analogIn); // read the input 3 times
	}
	uint16_t tmp;
	if (adcValue[0] > adcValue[1]) {
		tmp = adcValue[0];
		adcValue[0] = adcValue[1];
		adcValue[1] = tmp;
	}
	if (adcValue[1] > adcValue[2]) {
		tmp = adcValue[1];
		adcValue[1] = adcValue[2];
		adcValue[2] = tmp;
	}
	if (adcValue[0] > adcValue[1]) {
		tmp = adcValue[0];
		adcValue[0] = adcValue[1];
		adcValue[1] = tmp;
	}
	return adcValue[1];
}

void timer_sw_poll(void) {
	if (power_down) return;
	if (!digitalRead(SW_STBY)) {
		if (cnt_off_press == 100) {
			setOff(!off);
		}
		if (cnt_off_press == 200 && power_source == POWER_LIPO) {
			setOff(true);
			power_down = true;
			return;
		}
		cnt_off_press = min(201, cnt_off_press+1);
	} else {
		if (cnt_off_press > 0 && cnt_off_press <= 100) {
			setStandby(!stby);
		}
		cnt_off_press = 0;
	}
	boolean t1 = !digitalRead(SW_T1);
	boolean t2 = !digitalRead(SW_T2);
	boolean t3 = !digitalRead(SW_T3);

	//simultanious push of multiple buttons 
	if (t1 + t2 + t3 > 1) {
		store_to = 255;
		store_invalid = true;
	} else if (error != NO_ERROR) {
		if (!(t1 |  t2 | t3)) {
			store_invalid = false;
		} else if (!store_invalid && t3) {
			error = NO_ERROR; //dismiss
			set_t_old = 0; //refresh set_t display
			store_invalid = true; //wait for release
		}
	} else {
		//all buttons released
		if (!(t1 |  t2 | t3)) {
			if (store_to != 255) {
				if (cnt_but_store <= 100) {
					set_t = stored[store_to];
					setStandby(false);
					updateEEPROM();
				}
			}
			store_to = 255;
			store_invalid = false;
			cnt_but_store = 0;
		} else
		//one button pressed
		if (!store_invalid) {
			store_to = t2 + 2*t3;
			if (cnt_but_store > 100) {
				if (set_t != stored[store_to] && !stby) {
					stored[store_to] = set_t;
					cnt_but_store = 100;
					updateEEPROM();
				}
			}
			cnt_but_store++;
		}
	}
	boolean sw_up = !digitalRead(SW_UP);
	boolean sw_down = !digitalRead(SW_DOWN);
	boolean sw_changed = (sw_up != sw_up_old) || (sw_down !=sw_down_old);
	sw_up_old = sw_up;
	sw_down_old = sw_down;
	if((sw_up && sw_down) || !(sw_up || sw_down)) {
		cnt_but_press = 0;
		return;
	}
	if(sw_up || sw_down) {
		cnt_but_press++;
		if((cnt_but_press >= 100) || sw_changed) {
			setStandby(false);
			if(sw_up && set_t < TEMP_MAX) set_t++;
			else if (sw_down && set_t > TEMP_MIN) set_t--;
			if(!sw_changed) cnt_but_press = 97;
			updateEEPROM();
		}
	}
}

void setStandby(boolean state) {
	if (stby_layoff) return;
	if (state == stby) return;
	stby = state;
	last_measured = cur_t;
	last_temperature_drop = millis();
	last_on_state = millis()/1000;
	EEPROM.update(1, stby);
}
void setStandbyLayoff(boolean state) {
	if (state == stby_layoff) return;
	stby_layoff = state;
	stby = false;
	last_measured = cur_t;
	last_on_state = millis()/1000;
}

void setOff(boolean state) {
	if (state == off) return;
	if (!state)
		analogWrite(HEATER_PWM, 0);
	else
		setStandby(false);
	if (power_source == POWER_USB && !state) {
		state = true; //don't switch on, if powered via USB
		setError(USB_ONLY);
	}
	last_on_state = millis()/1000;
	off = state;
	wasOff = true;
	last_measured = cur_t;
}

void printTemp(float t) {
	if (fahrenheit) {
		t = toFahrenheit(t);
	}
	if (t < 100) tft.write(' ');
	tft.print((int)t);
}

void display(void) {
	if (force_redraw) tft.fillScreen(BLACK);
	int16_t temperature = cur_t; //buffer volatile value
	boolean yell = stby || (stby_layoff && blink);
	tft.drawCircle(20,63,8, off?RED:yell?YELLOW:GREEN);
	tft.drawCircle(20,63,7,off?RED:yell?YELLOW:GREEN);
	tft.fillRect(19,55,3,3,BLACK);
	tft.drawFastVLine(20,53,10, off?RED:yell?YELLOW:GREEN);
	if (error != NO_ERROR) {
		if (error != error_old || force_redraw) {
			error_old = error;
			tft.setTextSize(1);
			tft.setTextColor(RED, BLACK);
			tft.setCursor(0,96);
			switch (error) {
				case EXCESSIVE_FALL:
					tft.print(F("Error: Temperature dropped\nTip slipped out?"));
					break;
				case NOT_HEATING:
					tft.print(F("Error: Not heating\nWeak power source or short"));
					break;
				case BATTERY_LOW:
					tft.print(F("Error: Battery low\nReplace or charge"));
					break;
				case USB_ONLY:
					tft.print(F("Error: Power too low\nConnect power >5V"));
					break;
				case NO_TIP:
					tft.print(F("Error: No tip connected\nTip slipped out?"));
					break;
			}
			tft.setTextSize(2);
			tft.setTextColor(YELLOW, BLACK);
			tft.setCursor(10,112);
			tft.print(F("         OK "));
			
			tft.setTextColor(RED, BLACK);
			tft.setCursor(36,26);
			tft.setTextSize(3);
			tft.print(F(" ERR  "));
		}
	} else {
		if (error != error_old || force_redraw) {
			tft.fillRect(0, 96, 160, 16, BLACK);
			error_old = NO_ERROR;
		}
		tft.setTextSize(2);
		tft.setCursor(15,112);
		tft.setTextColor(WHITE, BLACK);
		printTemp(stored[0]);
		tft.write(' ');
		printTemp(stored[1]);
		tft.write(' ');
		printTemp(stored[2]);
		
		if (set_t_old != set_t || old_stby != (stby || stby_layoff) || force_redraw) {
			tft.setCursor(36,26);
			tft.setTextSize(3);
			if (stby || stby_layoff) {
				old_stby = true;
				tft.setTextColor(YELLOW, BLACK);
				tft.print(F("STBY  "));
			} else {
				old_stby = false;
				set_t_old = set_t;
				tft.setTextColor(WHITE, BLACK);
				tft.write(' ');
				printTemp(set_t);
				tft.write(247);
				tft.write(fahrenheit?'F':'C');
				tft.fillTriangle(149, 50, 159, 50, 154, 38, (set_t < TEMP_MAX) ? WHITE : GRAY);
				tft.fillTriangle(149, 77, 159, 77, 154, 90, (set_t > TEMP_MIN) ? WHITE : GRAY);
			}
		}
		if (!off) {
#ifdef SHUTOFF_ACTIVE
			if (autopower) {
				int16_t tout;
				if (stby || stby_layoff) {
					tout = min(max(0,(last_on_state + OFF_TIMEOUT - (millis())/1000)), OFF_TIMEOUT);
				} else {
					tout = min(max(0,(last_temperature_drop + STANDBY_TIMEOUT - (millis())/1000)), STANDBY_TIMEOUT);
				}
				tft.setTextColor(stby?RED:YELLOW, BLACK);
				tft.setTextSize(2);
				tft.setCursor(46,78);
				if (tout < 600) tft.write('0');
				tft.print(tout/60);
				tft.write(':');
				if (tout%60 < 10) tft.write('0');
				tft.print(tout%60);
			}
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
void loop(void) {
	analogWrite(HEAT_LED, pwm);
	//Switch to following if the oscillation of the led bothers you
	//digitalWrite(HEAT_LED, cur_t+5 < target || (abs((int16_t)cur_t-(int16_t)target) <= 5 && (millis()/(stby?1000:500))%2));
	
	if (sendNext <= millis()) {
		sendNext += 100;
#ifndef TEST_ADC
		Serial.print(stored[0]);
		Serial.print(";");
		Serial.print(stored[1]);
		Serial.print(";");
		Serial.print(stored[2]);
		Serial.print(";");
		Serial.print(off?0:1);
		Serial.print(";");
		Serial.print(error);
		Serial.print(";");
		Serial.print(stby?1:0);
		Serial.print(";");
		Serial.print(stby_layoff?1:0);
		Serial.print(";");
		Serial.print(set_t);
		Serial.print(";");
		Serial.print(cur_t);
		Serial.print(";");
		Serial.print(pid_val);
		Serial.print(";");
		Serial.print(v_c2>1.0?v_c1:0.0);
		Serial.print(";");
		Serial.print(v_c2);
		Serial.print(";");
		Serial.println(v);
#endif
		Serial.flush();
		display();
	}
	if (Serial.available()) {
		uint16_t t = 0;
		switch (Serial.read()) {
			//Set new Temperature (eg. S350 to set to 350C)
			case 'T':
				if (Serial.available() >= 3) {
					t = serialReadTemp();
					//Serial.println(t);
					if (t <= TEMP_MAX && t >= TEMP_MIN) {
						set_t = t;
						updateEEPROM();
					}
				}
				break;
			//Store new Preset (eg. P1200 to store 200C to Preset 1, NOT 0 indexed)
			case 'P':
				if (Serial.available() >= 4) {
					uint8_t slot = Serial.read()-'1';
					if (slot < 3) {
						t = serialReadTemp();
						if (t <= TEMP_MAX && t >= TEMP_MIN) {
							stored[slot] = t;
							updateEEPROM();
						}
					}
				}
				break;
			//Clear errors
			case 'C':
				error = NO_ERROR;
				break;
			//Set standby
			case 'S':
				setStandby(Serial.read() == '1');
				break;
			//Set on/off
			case 'O':
				setOff(Serial.read() == '0');
				break;
		}
	}
	delay(DELAY_MAIN_LOOP);
	if (power_down) {
		powerDown();
	}
}

uint16_t serialReadTemp() {
	uint16_t t;
	uint8_t n;
	n = Serial.read()-'0';
	t = min(9, max(0, n))*100;
	n = Serial.read()-'0';
	t += min(9, max(0, n))*10;
	n = Serial.read()-'0';
	t += min(9, max(0, n))*1;
	return t;
}

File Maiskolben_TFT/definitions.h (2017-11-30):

#define VERSION			"3.1"
#define EE_VERSION      31
#define EEPROM_CHECK	42

#define BAR_HEIGHT       4 //Should be no bigger than 5

/*
 * TIPS ARE SPECIFIED FOR 450 DEGREE MAX
 * If read 1023 on Analog in, the tip is turned off automatically
 */
#define TEMP_MAX    450
#define TEMP_MIN    200
#define TEMP_STBY   150
#define TEMP_COLD   (adc_offset + 15)

#define SHUTOFF_ACTIVE
#define BOOTHEAT_ACTIVE

#define STANDBY_TIMEOUT 240 // seconds without any significant temperature drop, if exceeded it will standby
#define OFF_TIMEOUT     900 // seconds in standby before turning off

#define TEMP_RISE             30 //threshold temperature, that must be exceeded delta in given time:
#define TEMP_UNDER_THRESHOLD  80 // x (TIME_COMPUTE_IN_MS + DELAY_BEFORE_MEASURE)
#define THRES_MAX_DECEED       2 //max times the threshold temperature may be undercut by the current temperature

//Temperature in degree to rise at least in given time
#define TEMP_MIN_RISE         10
//Time in that the temperature must rise by the set temperature
#define TEMP_RISE_TIME      1000

//#define OLD_PWM

//      RX          0
//      TX          1
#define SW_STBY     2
#define HEATER_PWM  3
#define SW_DOWN     4
#define HEAT_LED    5
#define SW_UP       6
#define SW_T3       7
#define SW_T2       8
#define SW_T1       9
#define TFT_CS      10
//      MOSI        11
#define POWER       12 //use MISO PULLUP as switch
//      SCK         13
#define TEMP_SENSE  A0
#define STBY_NO     A1
#define BAT_C3      A2
#define BAT_C2      A3
#define BAT_C1      A4
#define TFT_DC      A5
#ifdef PIN_A7
#define CHARGEDET   A6
#define VIN         A7
#endif

#define kp          0.03
#define ki          0.00001
#define kd          0.0

#define TIME_COMPUTE_IN_MS          10
#define TIME_MEASURE_VOLTAGE_IN_MS 200
#define TIME_SW_POLL_IN_MS          10
#define DELAY_BEFORE_MEASURE        10
#define DELAY_MAIN_LOOP             10
#define PID_SAMPLE_TIME             10

#define ADC_TO_TEMP_GAIN             0.54 //default value if no calibration is performed
#define ADC_TO_TEMP_OFFSET          42.8  //default value if no calibration is performed

#define EEPROM_SET_T     8
#define EEPROM_VERSION  10
#define EEPROM_DISPLAY  11
#define EEPROM_OPTIONS  12
#define EEPROM_REVISION 13
#define EEPROM_ADCTTG   14
#define EEPROM_ADCOFF   (EEPROM_ADCTTG + sizeof(float))

#define EEPROM_INSTALL  42
#define REF_T1          275
#define REF_T2          410
#define DELTA_REF_T     (REF_T2 - REF_T1)


typedef enum POWER_SOURCE {
	NO_INIT,
	POWER_USB,
	POWER_CORD,
	POWER_LIPO,
	POWER_CHARGING
} p_source;
typedef enum ERROR_TYPE {
	NO_ERROR,
	EXCESSIVE_FALL,
	NOT_HEATING,
	NO_TIP,
	BATTERY_LOW,
	USB_ONLY
} error_type;

const unsigned char power_cord [] PROGMEM =  {
	0x00, 0x00, 0xC0,
	0x00, 0xFF, 0xC0,
	0x01, 0xFF, 0xDF,
	0x03, 0xFF, 0xDF,
	0xFB, 0xFF, 0xC0,
	0x03, 0xFF, 0xDF,
	0x01, 0xFF, 0xDF,
	0x00, 0xFF, 0xC0,
	0x00, 0x00, 0xC0
};
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

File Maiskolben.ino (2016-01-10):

#include <SPI.h>
#include <Adafruit_GFX.h>
#include <Adafruit_PCD8544.h>
#include <EEPROM.h>
#include "TimerOne.h"

#define VERSION	100
#define EEPROM_CHECK 42

#define STBY_TEMP	150
//SOFTWARE CAN'T MEASURE MORE THAN 422, IF SET TO >= 422 IT'S LIKELY TO KILL YOUR TIP!
//If read 1024 on Analog in, the tip is turned off.
#define MAX_TEMP	400
#define MIN_TEMP	100

//Temperature in degree to rise at least in given time
#define TEMP_MIN_RISE 10
//Time in that the temperature must rise by the set temperature
#define TEMP_RISE_TIME 1000

#define HEATER_PWM	3
#define SW_T1		5
#define SW_T2		6
#define SW_T3		7
#define TEMP_SENSE	A0
#define STBY_NO		A1
#define SW_STBY		A2
#define HEAT_LED	A3
#define SW_DOWN		A4
#define SW_UP		A5
#define BATTERY_IN	A6

#define TIME_DISP_REFRESH_IN_MS 300
#define TIME_SW_POLL_IN_MS 10
#define DELAY_BEFORE_MEASURE 10
#define DELAY_MAIN_LOOP 10

#define ADC_TO_TEMP_GAIN 0.39
#define ADC_TO_TEMP_OFFSET 23.9
#define CTRL_GAIN 10

#define NUM_DIFFS 8 //Dividable by 8

boolean off = true, stby = true, stby_layoff = true, sw_stby_old = false, sw_up_old = false, sw_down_old = false, clear_display = true, store_invalid = true, error = false, menu = false;
uint16_t stored[3] = {250, 300, 350}, set_t = 150, cur_t, set_t_old, cur_t_old;
uint8_t pwm, store_to = 255, contrast = 50;
uint16_t cnt_disp_refresh = TIME_DISP_REFRESH_IN_MS, cnt_sw_poll, cnt_but_press, cnt_off_press, cnt_but_store;
float battery_voltage;
uint16_t last_measured;
int16_t last_diffs[NUM_DIFFS];
uint8_t array_index, array_count;

Adafruit_PCD8544 display = Adafruit_PCD8544(10, 9, -1);

void setup() {
	digitalWrite(HEATER_PWM, LOW);
	pinMode(HEATER_PWM, OUTPUT);
	pinMode(HEAT_LED, OUTPUT);
	pinMode(TEMP_SENSE, INPUT);
	pinMode(SW_T1, INPUT_PULLUP);
	pinMode(SW_T2, INPUT_PULLUP);
	pinMode(SW_T3, INPUT_PULLUP);
	pinMode(SW_UP, INPUT_PULLUP);
	pinMode(SW_DOWN, INPUT_PULLUP);
	pinMode(STBY_NO, INPUT_PULLUP);
	pinMode(SW_STBY, INPUT_PULLUP);
	
	for (uint8_t i = 0; i < NUM_DIFFS; i++) {
		last_diffs[i] = 0;
	}
	
	//PWM Prescaler = 1024
	TCCR2B = TCCR2B & 0xFF;

	display.begin();
	display.clearDisplay();
	if (EEPROM.read(0) != EEPROM_CHECK) {
		EEPROM.update(0, EEPROM_CHECK);
		updateEEPROM();
	}
	stby = EEPROM.read(1);
	for (uint8_t i = 0; i < 3; i++) {
		stored[i] = EEPROM.read(2+i*2) << 8;
		stored[i] |= EEPROM.read(3+i*2);
	}
	set_t = EEPROM.read(8) << 8;
	set_t |= EEPROM.read(9);
	setContrast(EEPROM.read(10));
	delay(500);
	
	
	Serial.begin(115200);
	Serial.println("DIFF SUM;SET TEMPERATURE;IS TEMPERATURE;DUTY CYCLE;VOLTAGE");
	last_measured = getTemperature();
	Timer1.initialize(1000);
	Timer1.attachInterrupt(timer_isr);
}

void updateEEPROM() {
	EEPROM.update(1, stby);
	for (uint8_t i = 0; i < 3; i++) {
		EEPROM.update(2+i*2, stored[i] >> 8);
		EEPROM.update(3+i*2, stored[i] & 0xFF);
	}
	EEPROM.update(8, set_t >> 8);
	EEPROM.update(9, set_t & 0xFF);
	EEPROM.update(10, contrast);
}

void setContrast(uint8_t value) {
	if (value == 255) value = 0;
	contrast = min(100, value);
	EEPROM.update(10, contrast);
	display.setContrast(contrast);
}

int getTemperature() {
	analogWrite(HEATER_PWM, 0); //switch off heater
	delay(DELAY_BEFORE_MEASURE); //wait for some time (to get low pass filter in steady state)
	uint16_t adcValue = analogRead(TEMP_SENSE); // read the input
	if (adcValue >= 1015) { //Illegal value
		analogWrite(HEATER_PWM, 0);
		return 999;
	} else {
		analogWrite(HEATER_PWM, pwm); //switch heater back to last value
	}
	//return 124;
	return round(((float) adcValue)*ADC_TO_TEMP_GAIN+ADC_TO_TEMP_OFFSET); //apply linear conversion to actual temperature
}

void timer_sw_poll() {
	stby_layoff = !digitalRead(STBY_NO);
	if (!digitalRead(SW_STBY)) {
		if (cnt_off_press == 100) {
			setOff(!off);
		}
		cnt_off_press = min(101, cnt_off_press+1);
	} else {
		if (cnt_off_press > 0 && cnt_off_press != 101) {
			setStandby(!stby);
		}
		cnt_off_press = 0;
	}
	boolean t1 = !digitalRead(SW_T1);
	boolean t2 = !digitalRead(SW_T2);
	boolean t3 = !digitalRead(SW_T3);

	//simultanious push of multiple buttons 
	if (t1 + t2 + t3 > 1) {
		if (store_to != 255) cnt_but_store = 0;
		cnt_but_store = min(cnt_but_store+1, 255);
		store_to = 255;
		store_invalid = true;
		if (cnt_but_store > 100) {
			menu = true;
			clear_display = true;
		}
	} else if (menu) {
		if (t1 + t2 + t3 > 1) {
			store_invalid = true;
		} else if (!(t1 |  t2 | t3)) {
			store_invalid = false;
		} else if (!store_invalid) {
			if (t3) {
				store_invalid = true;
				menu = false;
				clear_display = true;
			}
		}
	} else if (error) {
		if (!(t1 |  t2 | t3)) {
			store_invalid = false;
		} else if (!store_invalid && t3) {
			error = false; //dismiss
			store_invalid = true; //wait for release
			clear_display = true;
		}
	} else if (!off) {
		//all buttons released
		if (!(t1 |  t2 | t3)) {
			if (store_to != 255) {
				if (cnt_but_store <= 100) {
					set_t = stored[store_to];
					setStandby(false);
					updateEEPROM();
				}
			}
			store_to = 255;
			store_invalid = false;
			cnt_but_store = 0;
		} else
		//one button pressed
		if (!store_invalid) {
			store_to = t2 + 2*t3;
			if (cnt_but_store > 100) {
				if (set_t != stored[store_to] && !stby) {
					stored[store_to] = set_t;
					cnt_but_store = 100;
					clear_display = true;
					updateEEPROM();
				}
			}
			cnt_but_store++;
		}
	}
	boolean sw_up = !digitalRead(SW_UP);
	boolean sw_down = !digitalRead(SW_DOWN);
	boolean sw_changed = (sw_up != sw_up_old) || (sw_down !=sw_down_old);
	sw_up_old = sw_up;
	sw_down_old = sw_down;
	if(sw_up && sw_down || !(sw_up || sw_down)) {
		cnt_but_press = 0;
		return;
	}
	if(sw_up || sw_down) {
		cnt_but_press++;
		if((cnt_but_press >= 100) || sw_changed) {
			if (menu) {
				if(sw_up) setContrast(contrast+1);
				else setContrast(contrast-1);
				if(!sw_changed) cnt_but_press = 70;
			} else if (!off) {
				setStandby(false);
				if(sw_up && set_t < MAX_TEMP) set_t++;
				else if (sw_down && set_t > MIN_TEMP) set_t--;
				if(!sw_changed) cnt_but_press = 97;
				updateEEPROM();
			}
		}
	}
}

void setStandby(boolean state) {
	if (state == stby) return;
	stby = state;
	//clear_display = true;
	last_measured = cur_t;
	EEPROM.update(1, stby);
}

void setOff(boolean state) {
	if (state == off) return;
	if (!state)
		analogWrite(HEATER_PWM, 0);
	off = state;
	clear_display = true;
	last_measured = cur_t;
}
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

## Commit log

2016-06-23 Version 2.1
    GUI not working with 2.1
    [Maiskolben_TFT.ino, definitions.h]
2016-09-28 Upgrade to 2.3
    Compatibility for new displays - if you upgrade you will be asked if
    the screen shows blue or red.
    Improved the temperature measurement, the 100k pulldown altered the
    measurement, so the temperature was 30-50°C hotter than measured.
    Based on this measurement error, you can now officially set the max
    temperature of 450°C.
    Removed misleading offset temperature, if colder than 50°C it only
    shows cold.
    Added direct heating on boot and option to disable this and auto
    shutdown. Just press the power button when booting (led blinking).
    Powering the tip will no longer heat to standby, even if it was in
    standby before.
    Added installation routine, do not use if you don’t know what y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
    [Maiskolben_TFT.ino, definitions.h]
2016-10-08 Added Maiskolben DIY, Case and 2.4 Update
    Added Gerber- and Eagle-Files for DIY-Maiskolben, Lasercut-Files for
    Maiskolben TFT (DIY Case is in progress) and upgraded Software to 2.4:
    Changed display of DC input to power cord, which will change from red
    (< 12V) to green (> 14.5V) to symbolize a good power supply and
    circumvent the wrong displayed voltage by voltage-divider with a
    maximum measurable VIN of 14.79 V. Therefore added a power cord icon.
    Removed debugging output.
    [Maiskolben_Lasercut.dxf, Maiskolben_THT.brd, Maiskolben_THT.csv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]
2016-11-02 Fixed 3v3 connection
    [Maiskolben_THT.brd, Maiskolben_THT.sch]
2016-11-10 Added Displayfix
    A fix to compensate power supply problems (white display on boot)
2016-12-02 Added outline-dxf for Maiskolben (SMD)
    [Maiskolben_outlines.dxf]
2016-12-02 Removed grouping
    [Maiskolben_outlines.dxf]
2016-12-04 Added 3D-File
    [Maiskolben.obj]
2016-12-05 Hooray, v2.5
    New temperature measurement (again…), show the effective heat power in
    watts, advanced features for Rev. 3.x (more to come), some private
    features for testing
2017-01-21 Push to HW V1.3
    Closes #3, adds drill file (whoops), adds optional LM7805 for v > 12V
    [Maiskolben_THT.brd, Maiskolben_THT.csv, Maiskolben_THT.sch]
2017-03-05 Added Maiskolben THT Case + Spongeholder
    Finally closes #2, but is case currently untested (should be working
    fine...)
    [Maiskolben_Spongeholder.stl, Maiskolben_THT_Button_Cap_x16.stl, Maiskolben_THT_Lasercut.dxf]
2017-03-05 Updated Case
    "Should be working" was the right text - should but wasn't
    [Maiskolben_THT_Lasercut.dxf]
2017-03-05 Added 3D Model of Lasercut File
    And removed a small edge and added a notch for USB-cables
    [Maiskolben_THT_Lasercut.dxf, Maiskolben_THT_Lasercut_3DView.stl]
2017-03-05 Merge dxf to stl
    Added the notch for USB to the sol too
    [Maiskolben_THT_Lasercut_3DView.stl]
2017-03-09 Referenced TFT-Blank issue, modified notch for case
    Even deeper notch as the USB-Cable has no chance to be plugged in
    otherwise.
    Referenced white-screen issues in Maiskolben_Mechaincal/README.md and
    added a software fix, bump to V2.7
    [Maiskolben_THT_Lasercut.dxf]
2017-06-01 Refactoring, higher temperature bar, correct EEPROM update
    - EEPROM autoboot/auto shutdown was set to auto shutdown when updating
    temperature
    - Indentation for definition.h altered
    - More constants
    - Better constant names
    - Individual temperature bar height
    - Starting bar at TEMP_COLD
    - Higher "cold" temperature
    [Maiskolben_TFT.ino, definitions.h]
2017-09-27 V3.0
    - Geänderte Display-Bibliothek (vgl. Abschnitt Bibliotheken der Readme)
    - Mehr Strings im Flash statt im RAM
    - Anpassungen um einen Maiskolben V3.2 im LiPo-Betrieb vollständig
    abzuschalten
    - Limitierung der Minimaltemperatur auf 200°C
    - `°C` wird mit bei Soll- und Ist-Temperatur angezeigt
    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
2017-11-30 Added option to set °C or °F; fixed EEPROM issue
    In boot menu you can now choose to display either celsius or farenheit.
    An issue was fixed which loaded illegal values from EEPROM for ADC
    offset and gain.
    [Maiskolben_TFT.ino, definitions.h]
2020-05-03 Update to current values
    Closes #13

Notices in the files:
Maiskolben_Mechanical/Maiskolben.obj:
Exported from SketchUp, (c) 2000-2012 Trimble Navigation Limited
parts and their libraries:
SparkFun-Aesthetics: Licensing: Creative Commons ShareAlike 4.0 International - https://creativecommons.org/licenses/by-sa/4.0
